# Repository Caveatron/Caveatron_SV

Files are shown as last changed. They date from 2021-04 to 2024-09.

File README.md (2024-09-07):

# Caveatron SV
 Survey-focused Caveatron model without LIDAR

## Key Features

- Electronic cave survey device
- Laser rangefinder up to 40 m
- Integrated digital compass and inclinometer
- LRUD and basic passage walls points measurements
- Fast Teensy processor
- File transfer to PC over USB
- Water/dust resistant 3D printed enclosure
- Custom printed circuit board

## What's New (2024-09-07)

SV Rev C is the current and preferred version and is the only one in active development. This version uses the faster Teensy 4.1 processor and has several enhancements including a new magnetometer module for much improved compass accuracy and reliability, a capacitive touchscreen, and faster battery charging.
A new revision of the Rev C board (C.2) has been posted with an RTC battery enhancement along with an updated bill of materials.

SV Rev A is based on the older Teensy 3.6 processor and is now deprecated and some components may no longer be available.

## Summary of Caveatron SV Directory Contents for each Revision

### Documentation
- Bill of Materials
- Assembly Instructions
- Wire Harness Assembly Instructions
- 3D Printed Parts Description

### PCB
- Schematic diagram
- KiCad files
- PCB gerber files

### Mechanical
- STL files for all 3D printed parts
- STEP files for all 3D printed parts

## These items can be found in other folders:

### Calibration
Info and calculators can be found at https://github.com/Caveatron/Calibration

### Software
Software can be found at https://github.com/Caveatron/Software

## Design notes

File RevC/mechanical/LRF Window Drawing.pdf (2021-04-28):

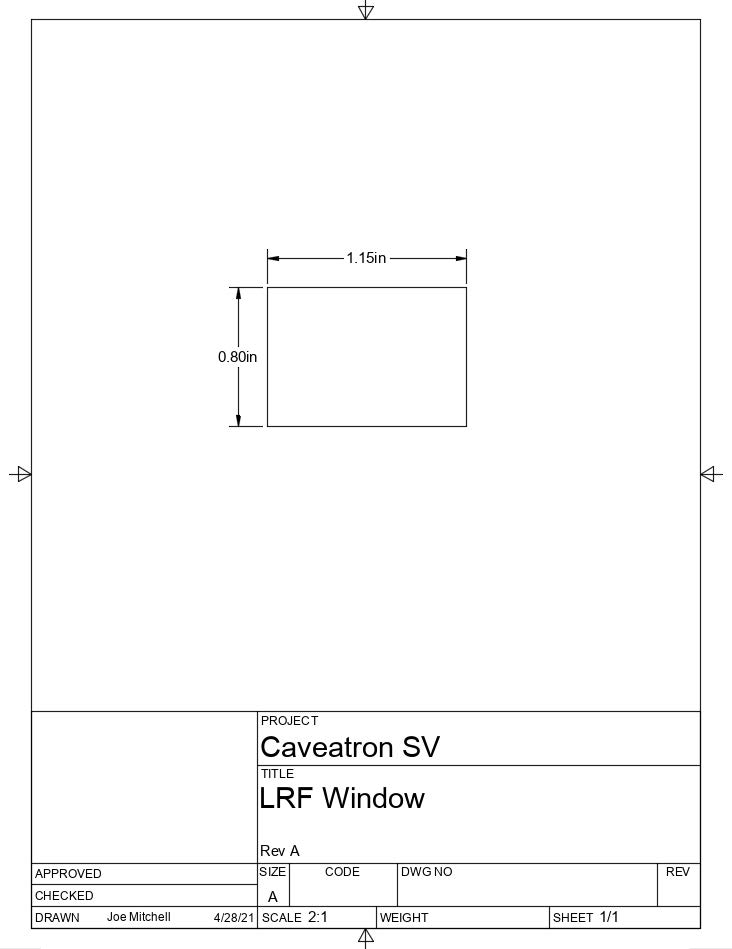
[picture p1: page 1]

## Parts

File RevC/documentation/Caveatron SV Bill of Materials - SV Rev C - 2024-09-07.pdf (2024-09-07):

### Caveatron SV Bill of Materials

Hardware Revision: C
Date: 2024-09-07
Item | Qty | Manufacturer | Mfr. P/N | Description | Suggested Vendor Link | Photo
Main Processor | 1 | PJRC Electronics | Teensy 4.1 | Teensy 4.1 | PJRC Store (https://www.pjrc.com/store/teensy41_pins.html)

Notes: The main system processor. Available from multiple vendors. Versions with and without the pins pre-installed are available (link above is with pins). Either of the versions (with or without Ethernet) are fine.
Touchscreen
LCD
1 | BuyDisplay | N/A | LCD 3.5” 320x480 TFT Display Module, OPTL Touch Screen w/Breakout Board
| | | Options: -Capacitive touch panel -16-bit 8080 40-pin header -3.3V supply -No font chip

BuyDisplay (https://www.buydisplay.com/lcd-3-5-inch-320x480-tft-display-module-optl-touch-screen-w-breakout-board)

Notes: The display and user interface. Note that this is the capacitive touchscreen version unlike the resistive version used previously.

Item | Qty | Manufacturer | Mfr. P/N | Description | Suggested Vendor Link
Photo

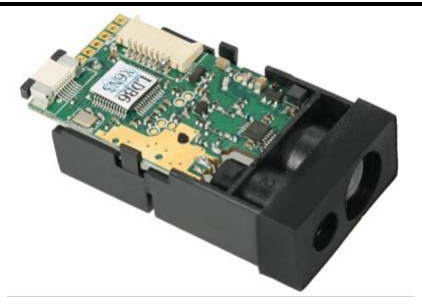
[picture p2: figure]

Laser Rangefinder | 1 | JRT Meter Tech., Co, Ltd. | Unknown | 40m – 60m Laser Distance Sensor Module | Egismos (https://www.egismos.com/laser-measuring-optoelectronics-module/laser-range-finder-distance-meter-4M) (HEX) Ebay (https://www.ebay.com/itm/314273830602) (ASCII) Alibaba (https://www.alibaba.com/product-detail/M88B-40m-Cheap-OEM-Chengdu-JRT_60644767746.html) (HEX) Alibaba (https://www.alibaba.com/product-detail/M88B-60m-Measuring-Sensor-Range-Finder_1600250111785.html) (HEX) Alibaba (https://www.alibaba.com/product-detail/Laser-Distance-Manufacturers-JRT-Smart-Distance_1600062036577.html) (probably HEX)
| | | | | Availability changes frequently. Sites linked above has availability as of the date of this BOM

Notes: Used for station distance measurements. There are several variants of this module including those that use ASCII or HEX-based commands both of which are supported by the Caveatron. Based on the datasheets I have reviewed I think any variant of this style should work.
Font/Graphics IC | 1 | Winbond | W25Q128JVSIM | W25Q128 SPI flash memory IC, 128 Mbit, quad 8-SOIC | Digikey (https://www.digikey.com/en/products/detail/winbond-electronics/W25Q128JVSIM/6819721) and many other source

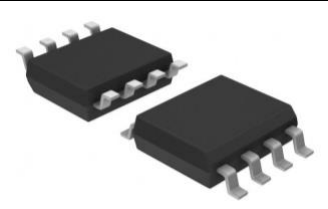
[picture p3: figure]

Notes: Contains the fonts and graphics used for the GUI. You must use the 128Mbit 8-SOIC package version – other sizes may not work. It is soldered to the pad location on the underside of the Teensy 4.1 that is directly under the micro-SD slot and farther from the edge (adjacent to the cross row of pins).

Item | Qty | Manufacturer | Mfr. P/N | Description | Suggested Vendor Link | Photo
Compass Module Optional but HIGHLY RECOMMENDED | 1 | Witmotion | RM3100 | WitMotion High-Precision RM3100 Military-grade Magnetometer Sensor | Amazon (https://www.amazon.com/High-Accuracy-Magnetometer-Geomagnetism-Military-Grade-High-Revolution/dp/B01N5QL0XC/) or Witmotion (https://www.wit-motion.com/geomagnetic-sensor/witmotion-high-precision-rm3100-military.html)

Notes: Used to determine the azimuth angle of the Caveatron. This is the best currently available low-cost magnetometer module option. This magnetometer has proven more accurate, reliable and with less drift than another other tested. It is optional since the Pololu IMU module below also includes a magnetometer but the Pololu magnetometer is much more noisy and less accurate, so it is highly recommended that you use this module.

IMU Module

Required for
accelerometer but
magnetometer
portion can be used
instead of RM3100
(not as good as
RM3100)
1 | Pololu | MinIMU-9 v5 (#2738)

MinIMU-9 v5 Gyro,
Accelerometer, Compass
(LSM6DS33, and LIS3MDL
Carrier)

Pololu (https://www.pololu.com/product/2738)

Notes: Used to determine orientation of the Caveatron and measure inclination.

Item | Qty | Manufacture r | Mfr. P/N | Description | Suggested Vendor Link | Photo
Battery Charger Module | 1 | Unknown | TP5000 | Lithium Ion 3.7V Charger Module | Amazon (https://www.amazon.com/Comimark-Charger-Lithium-LiFePO4-Charging/dp/B07XM7WT5M)

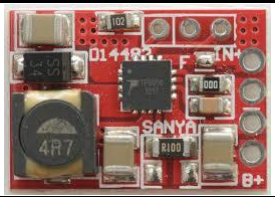
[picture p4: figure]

Notes: Battery charging module. There are several sources for this module and at least 2 variants. Be sure to get the variant with the 4 power pins all on the same side. A solder bridge is required to make it functional and a 0.2 ohm resistor can be added to increase the charge current above 1 Amp. These are usually on a red PCB but can also be green from other sources.
10k resistor | 2 | Various | Various | SMD resistor, 10k-ohm, 1%, 1206 package

Digikey (https://www.digikey.com/en/products/detail/stackpole-electronics-inc/RMCF1206FT10K0/1759669)

Notes: Resistor for battery monitor voltage divider and for IMU power input. Available from numerous manufacturers and vendors - the above is only 1 example. ¼ watt or less is fine since this carries no significant current.
3.3k resistor | 1 | Various | Various | SMD resistor, 3.3k-ohm, 1%, 1206 package

Digikey (https://www.digikey.com/en/products/detail/stackpole-electronics-inc/RMCF1206FT3K30/1753917)

Notes: Resistor for battery monitor voltage divider. Available from numerous manufacturers and vendors - the above is only 1 example. ¼ watt or less is fine since this carries no significant current.

Item | Qty | Manufacturer | Mfr. P/N | Description | Suggested Vendor Link | Photo
Battery Pack OPTION 1 | 1 | Dantona | L37A26-1-0-2WX | 18650 Lithium-Ion Battery Rechargeable (Secondary) 2.6Ah | Digikey (https://www.digikey.com/en/products/detail/dantona-industries/L37A26-1-0-2WX/13692682)

Notes: Primary system battery. This version comes with a 2-pin JST connector. A similar battery is available from Tenergy (PN 30011) but is not connectorized: Tenergy (https://power.tenergy.com/tenergy-li-ion-3-7v-2600mah-rechargeable-battery-pack-w-pcb-1s1p-9-62wh-3-5a-rate/) Battery Pack

OPTION 2

1 | Adafruit | 1781 | Lithium Ion Cylindrical Battery - 3.7v 2200mAh

Adafruit (https://www.adafruit.com/product/1781)

Notes: Primary system battery. This option is a lower capacity battery but might be an option if you are unable to obtain the higher capacity option above. Voltage
Regulator –
5V
1 | Pololu | 2119 | 5V Step-Up/Step-Down Voltage Regulator S7V7F5

Pololu (https://www.pololu.com/product/2119)

Notes: Power supply for Teensy. LRF
Voltage
Regulator
1 | Pololu | 2118 | Pololu Adjustable Step- Up/Step-Down Voltage Regulator S7V8A

Pololu (https://www.pololu.com/product/2118)

Notes: Power supply for Laser Rangefinder. Output needs to be set to 3.0V.

Item | Qty | Manufacturer | Mfr. P/N | Description | Suggested Vendor Link | Photo
Power Switch Module | 1 | Pololu | 2808 | Mini Pushbutton Power Switch with Reverse Voltage Protection, LV | Pololu (https://www.pololu.com/product/2808)

Notes: Turns on and off system power when pushbutton power switch is pressed and also controls timed auto power-off. 2.8V Voltage
Regulator

USED IN
PCB SV
REV C.2
1 | Microchip Technology

MCP1700-
2802E/TO

Linear voltage regulator IC, 2.8V, 250mA, TO92

Digikey (https://www.digikey.com/en/products/detail/microchip-technology/MCP1700-2802E-TO/2614902)

Notes: Regulates battery voltage to keep Real Time Clock active when Caveatron is turned off. Replaces coin cell battery used in PCB Rev C.2. 1uF Ceramic
Capacitor

USED IN
PCB SV
REV C.2
2 | TDK | FG18X7R1 E105KRT0
| | 6

Ceramic Capacitor, 1uF, 25V, Radial leads

Digikey (https://www.digikey.com/en/products/detail/tdk-corporation/FG18X7R1E105KRT06/5802875) (and
many others)

Notes: Stabilizes output voltage of RTC regulator above. Most any ceramic capacitor of 1 uF will work so long as it is rated to 6V or higher. Piezoelectric
Buzzer
1 | Uxcell | A1406240 0ux0199

uxcell A14062400ux0199 5 Pcs DC 2-28V 80Db Sound
Electronic Passive Buzzer Alarm Black, 22 x 4.5 mm

Amazon (https://www.amazon.com/gp/product/B01AJOESXG)

Notes: Indicator buzzer.

Item | Qty | Manufacturer | Mfr. P/N | Description | Suggested Vendor Link | Photo
| | Adafruit | 3350 | | Adafruit (https://www.adafruit.com/product/3350) Amazon (https://www.amazon.com/Momentary-Tri-Color-Button-Illuminated-Stainless/dp/B09FDD9KR9)

Power Switch
& Charging
LED

1

Rugged Metal Pushbutton -
16mm RGB Momentary

CIT Relay and
Switch
BH16NBSBG | Digikey (https://www.digikey.com/en/products/detail/cit-relay-and-switch/BH16NBSBG/12503457)

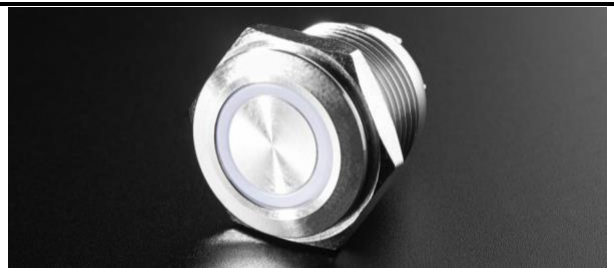
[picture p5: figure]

Notes: On/Off power switch and charge indicating ring LED. This one enables separate colors on the ring LED for indicating charging and charge complete. These can be found at other sources as well but if you buy from another source be sure to get the common anode version.
USB Jack | 1 | GT Contact | GT11A200-10 (RR-11A200-10)

Micro USB-B Plastic Panel
Mount to 6 Pin Solder Type

USBFirewire.
com (https://www.usbfirewire.com/parts/rr-11a200-10.html)

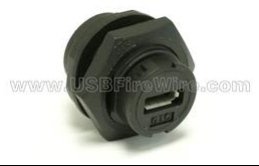
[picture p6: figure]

Notes: USB jack for data download, battery charging, and loading of software and calibration parameters. This is the version with the solder pins on the back side. If you prefer a USB-mini connector, that is available as part number RR-114200-10 (https://www.usbfirewire.com/parts/rr-114200-10.html) and is an identical fit.

Item | Qty | Manufacturer | Mfr. P/N | Description | Suggested Vendor Link | Photo

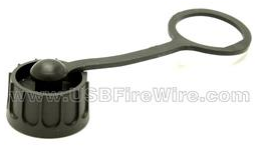
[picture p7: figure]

USB Cap | 1 | GT Contact | GT1C522122 (RR-1C522122) | Seal Cap | USBFirewire. com (http://www.usbfirewire.com/parts/rr-1c522122.html#RR-1C522122)

Notes: Waterproof cap for USB jack. This cap works for either the mini or micro USB options.

Item | Qty | Manufacturer | Mfr. P/N | Description | Suggested Vendor Link | Photo
GPS Module OPTIONAL (OPTION 1) | 1 | Adafruit | 746 | Adafruit Ultimate GPS Breakout - 66 channel w/10 Hz updates - PA1616S | Adafruit (https://www.adafruit.com/product/746) Digikey (https://www.digikey.com/en/products/detail/adafruit-industries-llc/746/5353613) and other sources

Notes: GPS module. This component adds GPS functionality to the Caveatron for marking entrances or surface features. Data is saved with the cave survey file and includes latitude, longitude, elevation, and position accuracy. Use of this module precludes use of the Bluetooth modules below.
Bluetooth
Module

OPTIONAL
(OPTION 2)
1 | Various | HM-10 | HM-10 Bluetooth Serial Module

Amazon (https://www.amazon.com/gp/product/B01G9KSAF6)

Notes: Bluetooth communications module. This component is intended for future interfacing with TopoDroid or similar software running on an Android tablet but this function has not yet been added. The HM-10 is a Bluetooth 4.0 LE device so is only compatible with newer tablets and draws less power. Multiple variants and vendors are available for this component and so long as it is an HM-10 and operates on +5V, it should work. Use of this module precludes use of the GPS module above.
Bluetooth
Module

OPTIONAL
(OPTION 3)
1 | Various | HC-05 | HC-05 Bluetooth Serial Module

Amazon (https://www.amazon.com/gp/product/B01G9KSAF6)

Notes: Bluetooth communications module. This component is intended for future interfacing with TopoDroid or similar software running on an Android tablet but this function has not yet been added. The HC-05 is a Bluetooth 2.0 device so is compatible with older tablets but draws more power. Multiple variants and vendors are available for this component and so long as it is an HC-05 and operates on +5V, it should work. Use of this module precludes use of the GPS module above.

MicroSD
Card
1 | Various | Various | SanDisk 32GB Ultra microSDHC UHS-I Memory Card

Amazon (https://www.amazon.com/dp/B073JWXGNT/)
and many other
sources

Notes: Storage for Caveatron data. Numerous brands and sources available. MicroSD card must be SDHC type not larger than 32 GB (smaller capacities are fine as well). SanDisk brand is preferred as they are generally the most reliable.
Item | Qty | Manufacturer | Mfr. P/N | Description | Suggested Vendor Link | Photo
Teensy USB connector | 1 | N/A | N/A | Micro USB Male Solder Connector | Amazon (https://www.amazon.com/Micro-USB-Connector-Conwork-Replacement/dp/B072MCHGXK) and many other sources

Notes: For the cable to connect the exterior USB jack to the Teensy. Wires are soldered between this part and the USB jack connector pins. Note that only the D+, D-, and GND are connected on this plug. The USB power (and a second GND wire) goes from the USB jack to a plug on the main PCB.

LCD
Connector
Cable
1 | N/A | N/A | 40 pin IDE Male to Female Extension Cable, 4” (10 cm) or 6” (15 cm)

Ebay (https://www.ebay.com/itm/170709721128)

and other sources

Notes: Cable to connect to LCD Touchscreen from the Caveatron main board. Cables longer than 6” would take up too much space in the enclosure while those shorter than 4” are not long enough. These are available from multiple vendors. Note that some of these connectors do not include one of the middle pins, however those are fine since that pin is not used.

Item | Qty | Manufacturer | Mfr. P/N | Description | Suggested Vendor Link | Photo
JST Connector 5-pin | 2 or 3 | Various | JST-XH | JST 2.54mm pitch, 5 pin, male connector | Amazon, Ebay and others

Notes: Connector for LRF and power switch. If you order them prewired as in the photo, be sure they are at least 100 mm in length. JST
Connector
2-pin
3 or 4 | Various | JST-XH | JST 2.54mm pitch, 2 pin, male connector

Amazon, Ebay and
others

Notes: Connector used for USB data, USB power, piezo buzzer, and battery. If you order them prewired as in the photo, be sure they are at least 100 mm in length. (You won’t need one for the battery if you order a battery that is pre-connectorized.
Socket
Headers 1

1
(6 pin
positions
needed)

Prec-Dip or
others

310-87-
106-41-
001101

Socket header, 0.1” pitch, 4.2 mm insulation height,
single row, 6 pins

Digikey (https://www.digikey.com/en/products/detail/preci-dip/310-87-106-41-001101/3757345)
and others

Notes: Header sockets for RM3100 magnetometer. Only needed if you are using the RM3100. Short header needed since the RM3100 has tall components. This header size is matched to the RM3100 brackets. Other variants with different numbers of pins are available. 4 pins are needed on one side and 2 pins on the other.
Socket
Headers 2

3
(54 pin
positions
needed)

Prec-Dip or
others

801-87-
024-10-
001101

Socket header, 0.1” pitch, 7.0 mm insulation height,
single row, 24 pins

Digikey (https://www.digikey.com/en/products/detail/preci-dip/801-87-024-10-001101/3757459)
and others

Notes: Header sockets for Teensy and IMU. Optional but this shorter size is preferred over the more common 8.51mm height to avoid interference with the display. Other variants with different numbers of pins are available. Two sets of 24 pins and 1 additional pin are needed for the Teensy and 5 pins are needed for the IMU module.

Item | Qty | Manufacturer | Mfr. P/N | Description | Suggested Vendor Link | Photo
Screen Protector | 1 | Supershieldz | N/A | iPhone SE and iPhone 5 Screen Protector | Amazon (https://www.amazon.com/gp/product/B00EOYMO66/)

Notes: Protection film for touchscreen. Needs to be cut to length. Most any PET screen protector film for iPhone 4, 4S, 5, 5s, or SE should work as they have the same screen width as the 3.5” LCD. Multiple vendors produce a similar product.
Threaded
Inserts for
Enclosure
4 | Initeq | #6-32 Threaded Heat Set Inserts for 3D Printing (Long)

Ebay (https://www.ebay.com/itm/20-pcs-6-6-32-Threaded-Heat-Inserts-for-3D-Printing-Plastic-Metal-6-32-Long/292301193578)

Notes: Heat set threaded inserts used in 3D printed enclosure. Threaded
Inserts for
external
mounting
(Optional)
1 | Initeq | #1/4-20 1/4" Threaded Heat Set Inserts for 3D Printing (Short)

Ebay (https://www.ebay.com/itm/20x-1-4-20-Brass-Threaded-Heat-Set-Inserts-for-Plastic-3D-Printing-Brass-Metal/292349851049)

Notes: Heat set threaded inserts used in 3D printed enclosure for external mounting. This is an optional part if you plan to attach something external to the Caveatron (like a handle) or mount it to a tripod.

Item | Qty | Manufacturer | Mfr. P/N | Description | Suggested Vendor Link | Photo
LRF Window Material | 1 | Sibe Polymers | 5064981212 | Clear Acrylic Plexiglass 12" x 12" - 3/32" (.090) | Amazon (https://www.amazon.com/gp/product/B01KABODQK/)

Notes: Transparent acrylic sheet for LRF window on Main Body. Wrist Strap
Lanyard
1 | Hukado | N/A | Hukado Adjustable Hand Wrist Straps Lanyard, (6 Pack) 9.5 inches Nylon Lanyard

Amazon (https://www.amazon.com/gp/product/B07Q2QDG3Q)

Notes: Wrist Strap. This wrist strap works well, but other options are available in various lengths depending on your preference.

O-Ring
Seals

4
feet

The O-Ring
Store
N50.103 | 0.103" (2.62mm) Buna-N 50 O-Ring Cord Stock, Black

O-Ring Store (https://www.theoringstore.com/store/index.php?main_page=product_info&cPath=117_527&products_id=40240)

Notes: O-Ring material for seals in main enclosure and LIDAR module. This 50 durometer material is preferred over more readily available 70 durometer since it is softer and can make a tighter seal. Must cut to length and glue ends (this vendor also sells O-ring glue in small quantities.) Other vendors sell similar material.

RTC Battery Holder

NOT
RECOMMENDED
Only used with
PCB SV Rev C.1

1 MPD and
others

BC501SM Coin Cell Battery Holder -12mm
(for CR1220 batteries)

Digikey (https://www.digikey.com/en/products/detail/mpd-memory-protection-devices/BC501SM/2439260)

Amazon (https://www.amazon.com/QMseller-CR1220-Horizontal-Battery-Container/dp/B07GXTQN75)

Notes: Holds a CR1220 battery to provide power to maintain the Real-time clock on the Teensy. The CR1220 batteries can only run the real-time clock for 6 weeks so require frequent replacement. A mod has been implemented to replace this part with a regulator and this part has been removed from PCB C.3 and C.4. Identical holders are available from many sources with differing part numbers.

Other Required Items:
Caveatron SV Rev C Printed Circuit Board
Single row male headers, 2.54 mm (0.1”) pitch
Double row female headers 2x20 (for 40 pin LCD Connector), 2.54 mm (0.1”) pitch Soldering supplies
6-32 x 1/2” Flat Head Screws (4x)
4-20 x ½” thread rolling screws (3x)
4-20 x ¼” thread rolling screws (10x) 2-28 x ¼” thread rolling screws (15x) PETG filament for 3D printed parts O-Ring grease
O-Ring epoxy
Flexible waterproof epoxy sealant Adhesive-backed foam
Tape (Kapton or cellophane)

Notes: For assembly and electrical interconnections between boards.

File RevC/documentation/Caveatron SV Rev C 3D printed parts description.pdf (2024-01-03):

## Caveatron SV Rev C 3D Printed Parts Description

2024-01-02

### Introduction

This document includes a description of the 3D printed parts for the Caveatron SV and notes on how to print them. Also included is information on how the 3D printed parts go together. Information on how to assemble all the other components is found in the Caveatron SV Assembly Instructions document.

### Scaling

In some Slicer software, these files must be scaled by 2540% though in others, they import correctly.

### General Printing Notes

The recommended material for these parts is PETG. Print settings were 0.2 mm resolution and 20% infill. PLA is not recommended as it is not as durable. ABS may work but is more rigid and brittle so screws and inserts may not work as well. Many parts can be printed without support material. There are a few parts where support material is recommended in a few spots and if you have the ability to insert supports only in selected locations, you do not need supports everywhere.

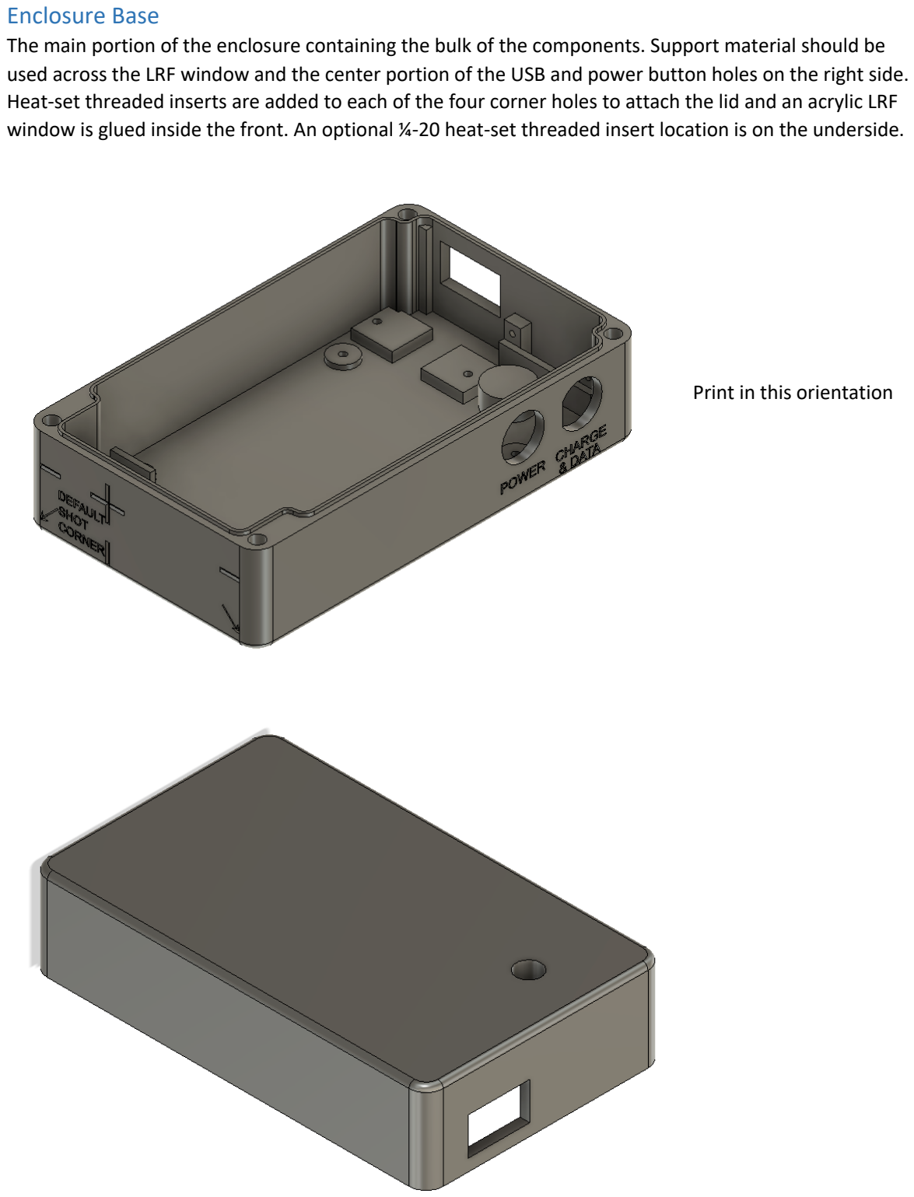
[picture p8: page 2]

### Enclosure Base

The main portion of the enclosure containing the bulk of the components. Support material should be used across the LRF window and the center portion of the USB and power button holes on the right side. Heat-set threaded inserts are added to each of the four corner holes to attach the lid and an acrylic LRF window is glued inside the front. An optional ¼-20 heat-set threaded insert location is on the underside.

Print in this orientation

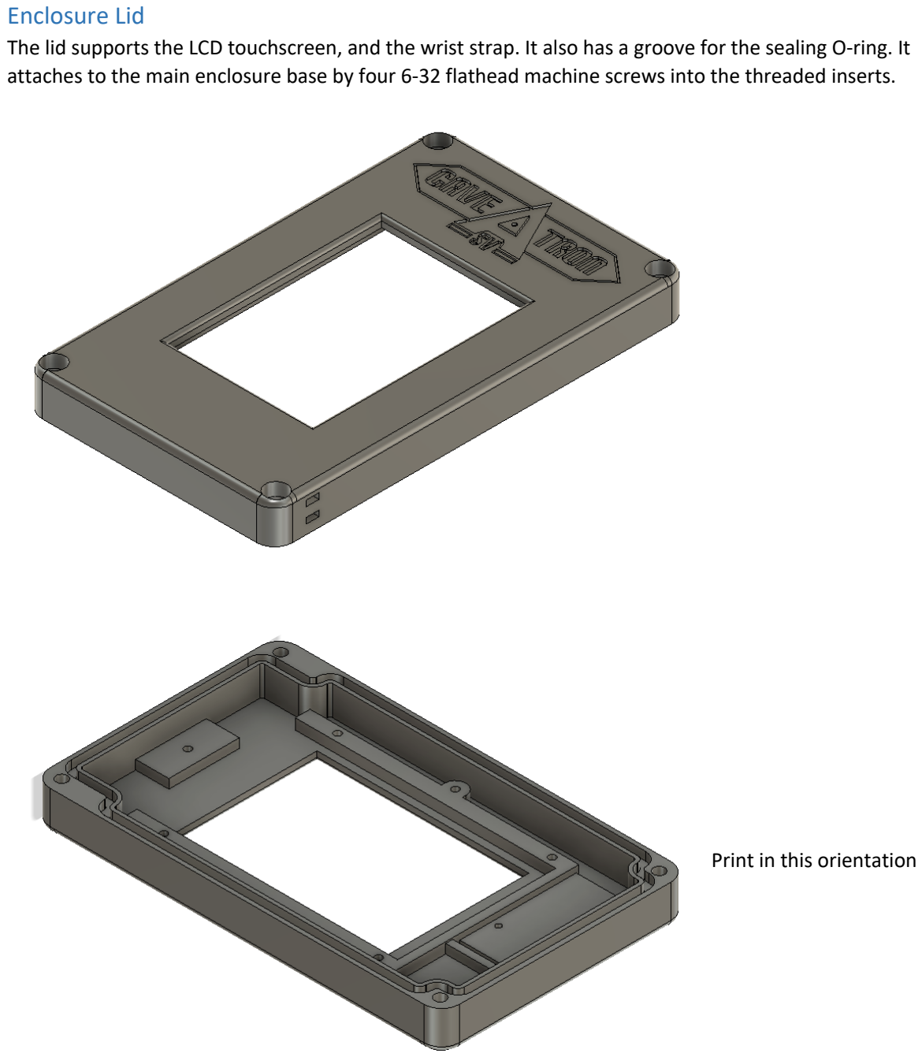
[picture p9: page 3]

### Enclosure Lid

The lid supports the LCD touchscreen, and the wrist strap. It also has a groove for the sealing O-ring. It attaches to the main enclosure base by four 6-32 flathead machine screws into the threaded inserts.

Print in this orientation

### LRF Cradle Bracket

The LRF module is supported by this bracket which in turn mounts to the inside of the Main Enclosure Base. A single 2-28 thread rolling screw inserted into the countersunk bottom center hole threads into the hole on the underside of the LRF module. The part is then mounted to the Main Enclosure base with two 4-20 thread rolling screws that are inserted into the countersunk holes on either side.

4-20 screws go in here; Toward LRF
The Cradle bracket attaches to the LRF

### LRF Clamp


Attaches to the top of the LRF bracket to fully secure the LRF module. Two 2-28 screws through the holes on either side attach to the top of the LRF bracket. The protrusion goes downward.

Flip over and 2-28 screw go through the holes.

Print in this orientation

The LRF clamp installs
in the marked holes.

module via a 2-28 screw through this hole.

window

### RM3100 Bracket

Provides support to the RM3100 magnetometer. 2-28 screws from the underside the main PCB screw into the two centermost holes in this part.


### RM3100 Clamp

Hold the RM3100 magnetometer securely to the bracket to prevent movement.


Be sure to get the orientation correct and adjust it so that it does not press on any components on the RM3100 board. The sloped corner goes toward the 40 pin connector for the touchscreen display.

Print in this orientation

2-28 screw threads
into the RM3100

Print in this orientation

### LCD Clamp

Provides additional support to the long side of the LCD modules. Two of these need to be printed.


A 4-20 thread rolling screw inserts through the LCD Clamp into threads into the hole indicated. The clamp is oriented so that the recessed part is down facing the LCD.

4-20 screw inserted through
the LCD Clamp threads in here.

Print in this orientation


### Buzzer Clamp

Secures the piezo buzzer in place.


This piece presses against backside of piezo buzzer (which is inserted into a slot at the bottom of the Main Enclosure Base). The Buzzer Clamp attaches to the Main Enclosure Base via two 2-28 thread rolling screws threaded into mounting points on the front of the enclosure.


### MinIMU Bracket

Secures the MinIMU module to the PCB.


This part does not directly attach to any other 3D part but instead attaches between MinIMU module and holes in the main PCB. Two 2-28 thread-rolling screws are inserted through the main PCB into the underside. The MinIMU attaches using one screw from the top.

Print in this orientation

The Cradle bracket installs to the enclosure base at the marked holes.

### Battery Clamp

Secures the battery in place. This part is attached to the underside of the Main Enclosure Lid with a single 4-20 thread rolling screw. Two small pieces of adhesive-backed foam should be attached to the side that presses down on the battery.


### GPS Bracket (Optional)

Secures the GPS module in place on the underside of the Main Enclosure Lid.


Printing requires supports to be enabled. It attaches with two 2-28 thread-rolling screws.

### Bluetooth Module Clamp (Optional)

Secures the Bluetooth module in place on the underside of the Main Enclosure Lid.


The cutout in this part fits over the Bluetooth module and holds it to the underside of the lid. It attaches with two 2-28 thread-rolling screws.

Print in this orientation

Print in this orientation

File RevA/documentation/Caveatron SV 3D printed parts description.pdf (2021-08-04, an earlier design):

## Caveatron SV Rev A 3D Printed Parts Description

2021-08-03

### Introduction

This document includes a description of the 3D printed parts for the Caveatron SV and notes on how to print them. Also included is information on how the 3D printed parts go together. Information on how to assemble all the other components is found in the Caveatron SV Assembly Instructions document.

### Scaling

To print properly, these files must be scaled by 2540% in your slicer software.

### General Printing Notes

The recommended material for these parts is PETG. Print settings were 0.2 mm resolution and 20% infill. PLA is not recommended as it is not as durable. ABS may work but is more rigid and brittle so screws and inserts may not work as well. Many parts can be printed without support material. There are a few parts were support material is recommended in a few spots and if you have the ability to insert supports only in selected locations, you do not need supports everywhere.


### Enclosure Base

The main portion of the enclosure containing the bulk of the components. Support material should be used across the LRF window and the center portion of the USB and power button holes on the right side. It contains holes for the heat-set threaded inserts for the lid screws and the option tripod mount.

Print in this orientation


### Enclosure Lid

The lid supports the LCD touchscreen, and the wrist strap. It also has a groove for the sealing O-ring. It attaches to the main enclosure base by four 6-32 flathead machine screws into the threaded inserts.

Print in this orientation

### LRF Cradle Bracket

The JRT LRF is placed into this bracket which attaches it to the Main Enclosure Base.

The Cradle bracket attaches to the LRF module via a screw through this hole.

A through-hole from the underside allows a 2-28 thread-rolling screw to be screwed into the hole in the LRF module. Two through holes on either side are for two 4-20 thread-rolling screws to affix the bracket to the Main Enclosure Base. The additional small holes on top are for attaching the LRF clamp. Note the orientation of the bracket when attaching the LRF and installing it into the Main Enclosure Base. The centered through-hole for the LRF needs to be toward the front window of the enclosure.

Print in this orientation

The LRF clamp installs
in the marked holes.


### LRF Clamp

Secures the LRF module in place.

It is flipped over from the orientation shown here to install on the top of the LRF cradle bracket using two 2-28 thread rolling screws. Be sure that the step at the rear of the part is downward and wraps over the similar step on the LRF itself.

Print in this orientation

The Cradle bracket installs to the enclosure base at the marked holes.

### LCD Clamp

Provides additional support to the long side of the LCD modules. Two of these need to be printed.


A 4-20 thread rolling screw inserts through the LCD Clamp into threads into the hole indicated. The clamp is oriented so that the recessed part is down facing the LCD.
4-20 screw inserted through the LCD Clamp threads in here.

Print in this orientation


### Buzzer Clamp

Secures the piezo buzzer in place.


This piece presses against backside of piezo buzzer (which is inserted into a slot at the bottom of the Main Enclosure Base). The Buzzer Clamp attaches to the Main Enclosure Base via two 2-28 thread rolling screws threaded into mounting points on the front of the enclosure.


### AltIMU Bracket

Secures the MinIMU or AltIMU module to the PCB.


This part does not directly attach to any other 3D part but instead attaches between IMU module and holes in the PCB using 2-28 thread-rolling screws inserted from the bottom of the PCB. One or two screws attach the IMU module to the bracket from the top. The MinIMU uses only one of the top screw holes in the bracket whereas the AltIMU uses both bracket holes.

Print in this orientation

The Cradle bracket installs to the enclosure base at the marked holes.

### Battery Clamp

Secures the battery in place. This part is attached to the underside of the Main Enclosure Lid with a single 4-20 thread rolling screw. Two small pieces of adhesive-backed foam should be attached to the side that presses down on the battery.


### Bluetooth Module Clamp (Optional)

Secures the Bluetooth module in place on the underside of the Main Enclosure Lid.


The cutout in this part fits over the Bluetooth module and holds it to the underside of the lid. It attaches with two 2-28 thread-rolling screws.

Print in this orientation

Print in this orientation

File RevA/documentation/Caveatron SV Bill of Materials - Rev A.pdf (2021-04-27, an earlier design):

### Caveatron SV Bill of Materials

Hardware Revision: A

### Date: 2021-04-18

All the parts in this list have been tested with the Caveatron and have either been integrated into the code or are planned to be. For some parts, alternate options are available.

Touchscreen LCD; BuyDisplay; LCD 3.5” 320x480; TFT Display Module, OPTL Touch Screen w/Breakout Board; Options: -Resistive touch panel -16-bit 8080 40-pin header -3.3V supply -No font chip; Notes: The display and user interface.

Item | Qty | Manufacturer | Mfr. P/N | Description | Suggested Vendor Link | Photo
Main Processor | 1 | PJRC Electronics | Teensy 3.6 | Teensy 3.6 | PJRC Store (https://www.pjrc.com/store/teensy36_pins.html)

Notes: The main system processor. Available from multiple vendors. Versions with and without the pins pre-installed are available (link above is with pins).

Item | Qty | Manufacturer | Mfr. P/N | Description | Suggested Vendor Link | Photo
Graphics Module (SPI Flash Memory) | 1 | Multiple (Winbond IC) | W25Q64 or similar | W25Q64 64Mbit 8MByte Flash Memory Module Data Flash SPI Interface | Amazon (https://www.amazon.com/NOYITO-W25Q64-64Mbit-DataFlash-Interface/dp/B07C4JN857)

Notes: Storage for fonts and graphics used in the GUI. SPI Flash memory must be Winbond W25Q32, W25Q64, or W25Q128 (memory size should be 32Mbit or higher.) Winbond W25Q16 (16 Mbit) could be used, but will only hold the fonts and not support the graphics.

Laser
Rangefinder

OPTION 3

1 | JRT Meter
Tech., Co, Ltd.
Unknown | 40m – 60m Laser
Distance Sensor
Module

Ebay (https://www.ebay.com/itm/laser-distance-meter-serial-module-TTL-RS232-laser-meter-sensor/292329869069)
Availability changes
frequently. Site
linked above has
availability as of the
date of this BOM

Notes: Used for station distance measurements. There are several variants of this module. Be sure to get the small one that is about 50 mm(2”) in length.

IMU/
Compass
Module

OPTION 1

1 | Pololu | MinIMU- 9 v5 (#2738)
| | Or
| | AltIMU- 10 v5 (#2739)

AltIMU-10 v3 Gyro,
Accelerometer,
Compass, and Altimeter
(L3GD20H, LSM303D,
and LPS331AP Carrier)

Pololu (https://www.pololu.com/product/2738)

Notes: Used to determine orientation of the Caveatron and measure azimuth and inclination. This is the best currently available IMU module option although the discontinued models below have half the noise floor if you can find them. The AltIMU-10 v5 is an equivalent part and can also be used (the altitude sensor is not used).

Item | Qty | Manufacturer | Mfr. P/N | Description | Suggested Vendor Link | Photo
Battery Pack OPTION 1 | 1 | Dantona | L37A26-1-0-2WX | 18650 Lithium-Ion Battery Rechargeable (Secondary) 2.6Ah | Digikey (https://www.digikey.com/en/products/detail/dantona-industries/L37A26-1-0-2WX/13692682)

Notes: Primary system battery. This version comes with a 2-pin JST connector. A similar battery is available from Tenergy (PN 30011) but is not connectorized: Tenergy (https://power.tenergy.com/tenergy-li-ion-3-7v-2600mah-rechargeable-battery-pack-w-pcb-1s1p-9-62wh-3-5a-rate/) Battery Pack

OPTION 2

1 | Adafruit | 1781 | Lithium Ion Cylindrical Battery - 3.7v 2200mAh

Adafruit (https://www.adafruit.com/product/1781)

Notes: Primary system battery. This option is a lower capacity battery but might be an option if you are unable to obtain the higher capacity option above. Bluetooth
Module

OPTIONAL
(OPTION 1)
1 | Various | HM-10 | HM-10 Bluetooth Serial Module

Amazon (https://www.amazon.com/gp/product/B01G9KSAF6)

Notes: Bluetooth communications module. This component is intended for future interfacing with TopoDroid or similar software running on an Android tablet but this function has not yet been added. The HM-10 is a Bluetooth 4.0 LE device so is only compatible with newer tablets and draws less power. Multiple variants and vendors are available for this component and so long as it is an HM-10 and operates on +5V, it should work.
Bluetooth
Module

OPTIONAL
(OPTION 2)
1 | Various | HC-05 | HC-05 Bluetooth Serial Module

Amazon (https://www.amazon.com/gp/product/B01G9KSAF6)

Notes: Bluetooth communications module. This component is intended for future interfacing with TopoDroid or similar software running on an Android tablet but this function has not yet been added. The HC-05 is a Bluetooth 2.0 device so is compatible with older tablets but draws more power. Multiple variants and vendors are available for this component and so long as it is an HC-05 and operates on +5V, it should work.

Item | Qty | Manufacturer | Mfr. P/N | Description | Suggested Vendor Link | Photo
Battery Charger Module | 1 | Unknown | Unknown | Lithium Ion 3.7V Charger Module | Amazon (https://www.amazon.com/Comimark-Charger-Lithium-LiFePO4-Charging/dp/B07XM7WT5M)


Notes: Battery charging module. There are several sources for this module and at least 2 variants. Be sure to get the variant with all the 4 power pins all on the same side to work with the Caveatron SV PCB. These are usually on a red PCB.

10k resistor | 2 | Various | Various | SMD resistor, 10k-ohm, 1%, 1206 package

Digikey (https://www.digikey.com/en/products/detail/stackpole-electronics-inc/RMCF1206FT10K0/1759669)


Notes: Resistor for battery monitor voltage divider and IMU power input. Available from numerous manufacturers and vendors - the above is only 1 example. ¼ watt or less is fine since this carries no significant current.

3.3k resistor | 1 | Unknown | Unknown | SMD resistor, 3.3k-ohm, 1%, 1206 package

Digikey (https://www.digikey.com/en/products/detail/stackpole-electronics-inc/RMCF1206FT3K30/1753917)


Notes: Resistor for battery monitor voltage divider. Available from numerous manufacturers and vendors - the above is only 1 example. ¼ watt or less is fine since this carries no significant current.

Item | Qty | Manufacturer | Mfr. P/N | Description | Suggested Vendor Link | Photo


Voltage Regulator – 5V | 1 | Pololu | 2119 | 5V Step-Up/Step-Down Voltage Regulator S7V7F5 | Pololu (https://www.pololu.com/product/2119)

Notes: Power supply for Teensy.


Voltage
Regulator –
Adjustable
1 | Pololu | 2118 | Pololu Adjustable Step- Up/Step-Down Voltage Regulator S7V8A

Pololu (https://www.pololu.com/product/2118)

Notes: Power supply for Laser Rangefinder. Output needs to be set to 3.0V.

Power
Switch
Module
1 | Pololu | 2808 | Mini Pushbutton Power Switch with Reverse Voltage Protection, LV

Pololu (https://www.pololu.com/product/2808)


Notes: Turns on and off system power when pushbutton power switch is presses and also controls timed auto power-off.

Item | Qty | Manufacturer | Mfr. P/N | Description | Suggested Vendor Link | Photo


Piezoelectric Buzzer | 1 | Uxcell | A1406240 0ux0199 | uxcell A14062400ux0199 5 Pcs DC 2-28V 80Db Sound Electronic Passive Buzzer Alarm Black, 22 x 4.5 mm | Amazon (https://www.amazon.com/gp/product/B01AJOESXG)

Notes: Indicator buzzer. This is a smaller size than the regular Caveatron buzzer

Power Switch
& Charging
LED
1 | Adafruit | 3350 | Rugged Metal Pushbutton - 16mm 6V RGB Momentary

Adafruit (https://www.adafruit.com/product/3350)

Amazon (https://www.amazon.com/gp/product/B07SLXNW15/)


Notes: On/Off power switch and charge indicating ring LED. This one enables separate colors on the ring LED for indicating charging and charge complete. Other 16mm momentary pushbutton switches from Adafruit are available with a single color LED, though they are longer in length, so may not fit well in the enclosure. If you buy from another source be sure to get the common anode version.

USB Jack | 1 | GT Contact | GT11420 0-10

Mini USB-B C2 size
Plastic Panel Mount

USBFirewire.
com (http://www.usbfirewire.com/parts/rr-114200-10.html#RR-114200-10)


Notes: Mini-USB jack for data download, battery charging, and loading of software and calibration parameters. This is the version with the solder pins on the inside.

Item | Qty | Manufacturer | Mfr. P/N | Description | Suggested Vendor Link | Photo
USB Cap | 1 | GT Contact | GT1C522 122 | Seal Cap | USBFirewire. com (http://www.usbfirewire.com/parts/rr-1c522122.html#RR-1C522122)

Notes: Waterproof cap for USB jack.

RTC Battery
Holder
1 | MPD and others

BC501S
M

Coin Cell Battery Holder
- 12mm
(for CR1220 batteries)

Digikey (https://www.digikey.com/en/products/detail/mpd-memory-protection-devices/BC501SM/2439260)

Amazon (https://www.amazon.com/QMseller-CR1220-Horizontal-Battery-Container/dp/B07GXTQN75)

Notes: Holds a CR1220 battery to provide power to maintain the Real-time clock on the Teensy 3.6. Identical holders are available from many sources with differing part numbers but those I have checked that are surface mount all have nearly identical dimensions so should work.

MicroSD
Card
1 | Various | Various | SanDisk 16GB Ultra microSDHC UHS-I Memory Card
Amazon (https://www.amazon.com/dp/B073K14CVB/)

Notes: Storage for Caveatron data. Numerous brands and sources available. MicroSD card must be SDHC type not larger than 32 GB. SanDisk brand is preferred as they are generally the most reliable.

Item | Qty | Manufacture r | Mfr. P/N | Description | Suggested Vendor Link | Photo
LCD Connector Cable | 1 | N/A | N/A | 40 pin IDE Male to Female Extension Cable, 4” (10 cm) or 6” (15 cm) | Ebay or Amazon

Notes: Cable to connect to LCD Touchscreen from the Caveatron main board. Cables longer than 6” would take up too much space in the enclosure while those shorter than 4” are not long enough. These are available from multiple vendors.

JST
Connector
5-pin
3 | Various | JST-XH | JST 2.54mm pitch, 5 pin, male connector
Amazon,
Ebay and
others

Notes: Connector for LRF, power switch, and Bluetooth module. If you order them prewired as in the photo, be sure they are at least 100 mm in length.

JST
Connector
2-pin

3 or
4
Various | JST-XH | JST 2.54mm pitch, 2 pin, male connector
Amazon,
Ebay and
others

Notes: Connector used for USB data, USB power, piezo buzzer, and battery. If you order them prewired as in the photo, be sure they are at least 100 mm in length. (You many not need one for the battery if you order a battery that is pre-connectorized

Item | Qty | Manufacturer | Mfr. P/N | Description | Suggested Vendor Link | Photo
Threaded Inserts for Enclosure | 10 | Initeq | | #6-32 Threaded Heat Set Inserts for 3D Printing (Long) | Amazon (https://www.amazon.com/gp/product/B077CH3GCM/)

Notes: Heat set threaded inserts used in 3D printed enclosure. Threaded
Inserts for
external
mounting
(Optional)
1 | Initeq | #1/4-20 1/4" Threaded Heat Set Inserts for 3D Printing (Short)

Amazon (https://www.amazon.com/gp/product/B077P4M1CM/)

Notes: Heat set threaded inserts used in 3D printed enclosure for external mounting. This is an optional part if you plan to attach something external to the Caveatron (like a handle) or mount it to a tripod.
2-28 Thread
Rolling
Screws
14 | Small Parts | 410 Stainless Steel Thread Rolling Screw for Plastic, Passivated Finish, Pan Head, Phillips Drive, #2-28 Thread Size, 1/4" Length

Amazon (https://www.amazon.com/gp/product/B00GDYAXM2/)

Notes: Screws for threading directly into 3D printed holes 4-20 Thread
Rolling
Screws
10 | Small Parts | 410 Stainless Steel Thread Rolling Screw for Plastic, Passivated Finish, Pan Head, Phillips Drive, #4-20 Thread Size, 1/4" Length

Amazon (https://www.amazon.com/gp/product/B00GDYB61Y/)

Notes: Screws for threading directly into 3D printed holes

Item | Qty | Manufacturer | Mfr. P/N | Description | Suggested Vendor Link | Photo
LRF Window Material | 1 | Sibe Polymers | 506498121 2 | Clear Acrylic Plexiglass 12" x 12" - 3/32" (.090) | Amazon (https://www.amazon.com/gp/product/B01KABODQK/)

Notes: Transparent acrylic sheet for Rangefinder window on Main Body. The 0.118” transparent acrylic sheets used for the LIDAR windows could be used as well if you don’t want to order this 0.090” thick sheet. Requires cutting to size.
Screen
Protector
1 | Supershieldz | N/A | iPhone SE and iPhone 5 Screen Protector
Amazon (https://www.amazon.com/gp/product/B00EOYMO66/)


Notes: Protection film for touchscreen. Needs to be cut to length. Most any PET screen protector film for iPhone 4, 4S, 5, 5s, or SE should work as they have the same screen width as the 3.5” LCD. Multiple vendors produce a similar product.

Item | Qty | Manufacturer | Mfr. P/N | Description | Suggested Vendor Link | Photo
Wrist Strap Lanyard | 1 | Hukado | N/A | Hukado Adjustable Hand Wrist Straps Lanyard, (6 Pack) 9.5 inches Nylon Lanyard | Amazon (https://www.amazon.com/gp/product/B07Q2QDG3Q)

Notes: Wrist Strap. This wrist strap works well, but other options are available in various lengths depending on your preference. O-Ring
Seals

4 ft The O-Ring Store

N50.103/
10

0.103" (2.62mm) Buna-N 50 O-Ring Cord Stock, 10' Piece, Black

O-Ring Store (https://www.theoringstore.com/store/index.php?main_page=product_info&cPath=117_527&products_id=53229)

Notes: O-Ring material for seals in main enclosure and LIDAR module. This 50 durometer material is preferred over more readily available 70 durometer since it is softer and can make a tighter seal. Must cut to length and glue ends (this vendor also sells O-ring glue in small quantities.) Other vendors sell similar material.

USB
Connection
Pins

OPTION 1

2 | Mill-Max | 0929-7 | Spring-loaded contacts – through- hole mount (Pogo pins)

Digikey (https://www.digikey.com/en/products/detail/mill-max-manufacturing-corp/0929-7-15-20-75-14-11-0/5722643)

Notes: Special pins to make connection to USB pads on underside of Teensy. This can be done with two pogo pins or with right angle pins and shorter header receptacles. Note that these pads have a 2 mm spacing instead of the usual 2.54 mm (0.1”) spacing. The pogo pin option is preferred.

USB
Connection
Pins

OPTION 2

1 | Harwin | M22-2531005 | Connector Header – through hole, right angle, 2mm | Digikey (https://www.digikey.com/en/products/detail/harwin-inc/M22-2531005/3728251)
1 | Samtec | SQT-102-01-L-S | Connector Receptacle – through hole, 2mm | Digikey (https://www.digikey.com/en/products/detail/samtec-inc/SQT-102-01-L-S/1108780)

Notes: Special pins to make connection to USB pads on underside of Teensy. This can be done with two pogo pins or with right angle pins and shorter header receptacles. Note that these pads have a 2 mm spacing instead of the usual 2.54 mm (0.1”) spacing.

Other Required Items:
PETG Filament for 3D Printing Caveatron SV Printed Circuit Board CR1220 Battery
Single row male headers
Single row female headers
Double row female headers 2x20 (for 40 pin LCD Connector) 6-32 x 1/2” Flat Head Screws (8x)
6-32 x 3/8” Pan Head Screws (4x)
6-32 x 9/16” Pan Head Screw (1x)
6-32 Nut (3x)
Adhesive-backed foam
Epoxy, sealant, and grease
Tape (Kapton or electrical)
Soldering supplies

Notes: For assembly and electrical interconnections between boards. Several sizes of standard hardware required. More information in assembly instructions.

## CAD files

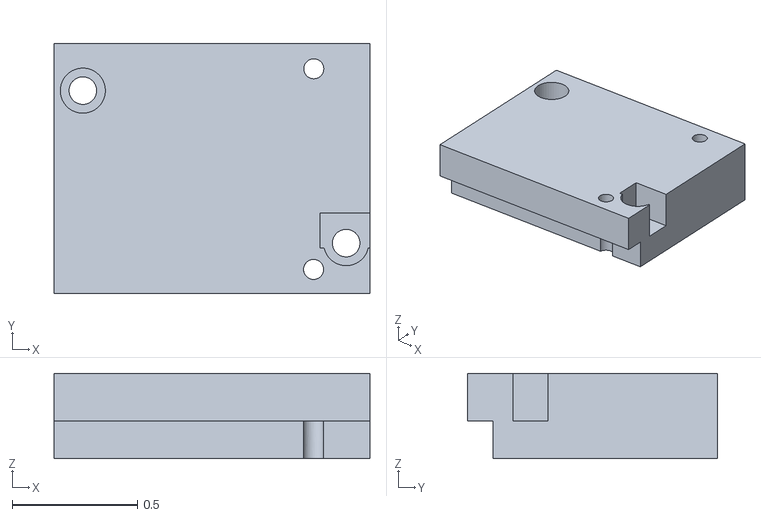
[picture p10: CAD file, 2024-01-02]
RevC/mechanical/GPS Bracket v2.stl
1.26 x 0.995 x 0.34

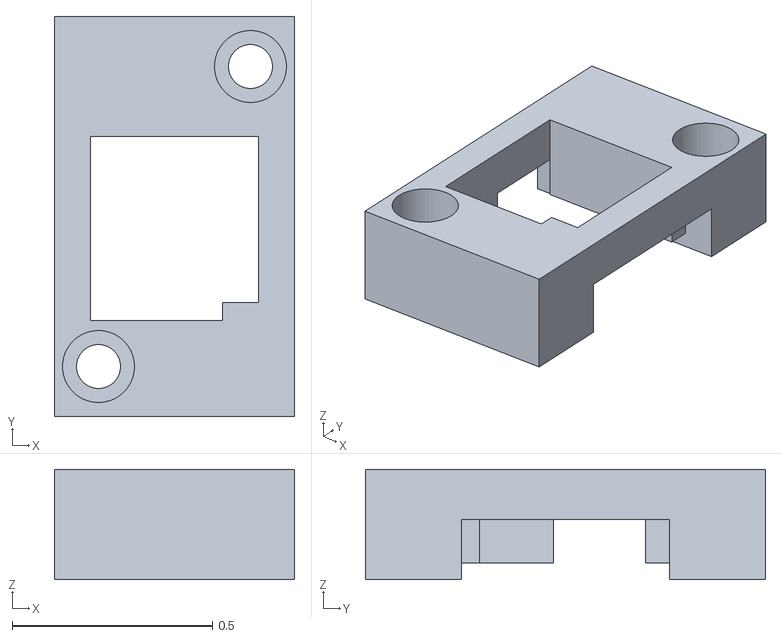
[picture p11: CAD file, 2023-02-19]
RevC/mechanical/RM3100 Cover_RevC v2.stl
0.6 x 1.00 x 0.275

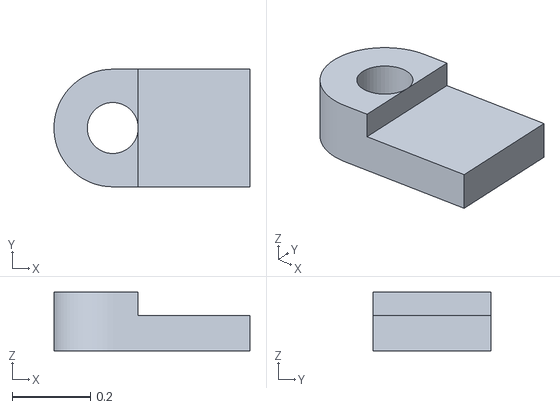
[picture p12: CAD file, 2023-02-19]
RevC/mechanical/LCD Clamp_RevC v3.stl
0.5 x 0.3 x 0.15

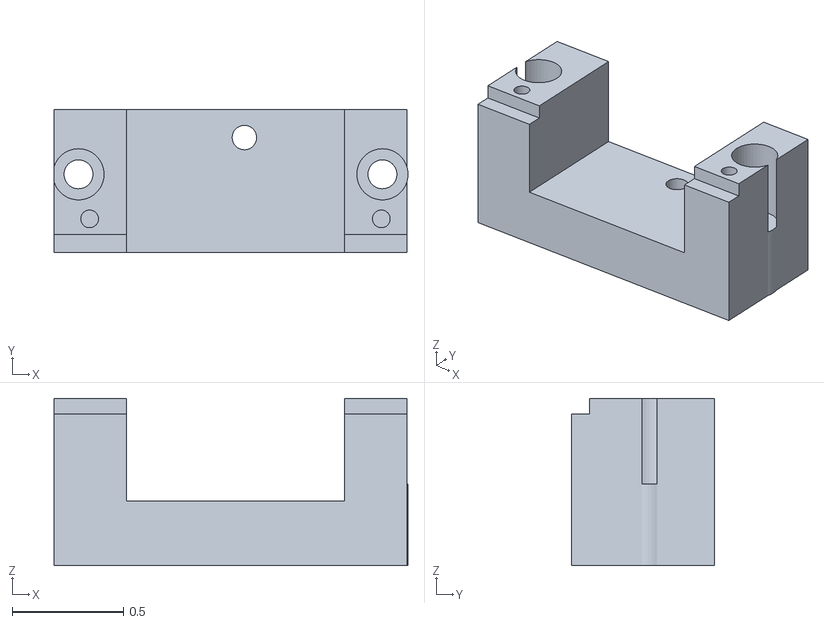
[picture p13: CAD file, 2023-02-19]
RevC/mechanical/LRF Bracket Base_RevC v1.stl
1.59 x 0.64 x 0.75

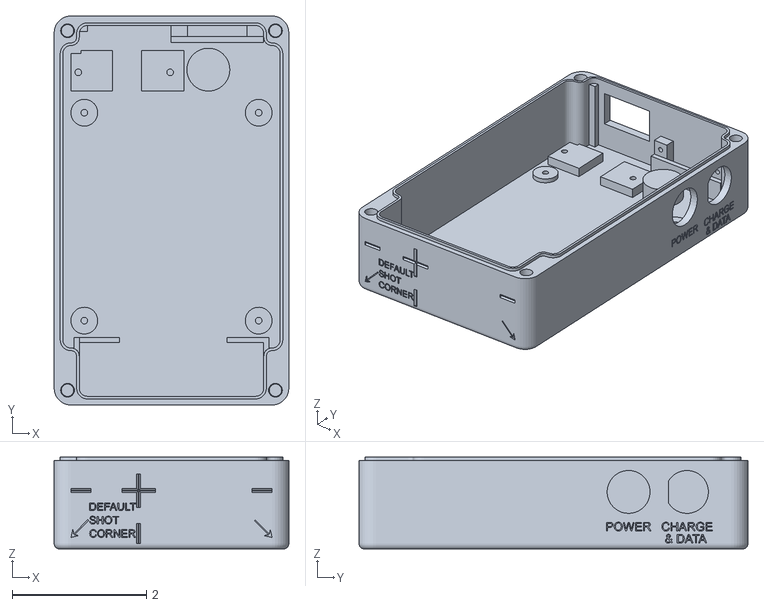
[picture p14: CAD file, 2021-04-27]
RevC/mechanical/Caveatron SV Enclosure Base v8.stl
3.50 x 5.80 x 1.37

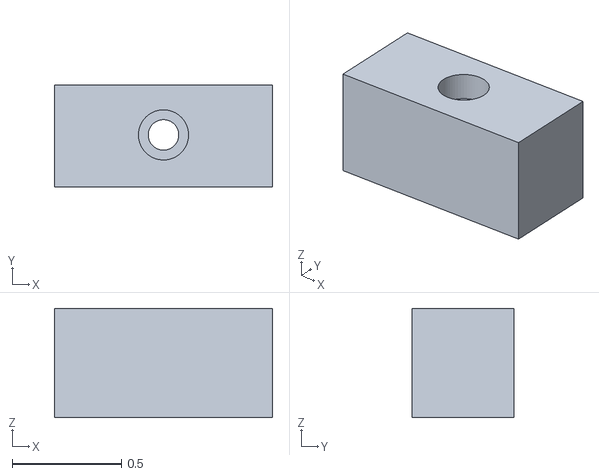
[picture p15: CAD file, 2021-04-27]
RevC/mechanical/Battery Clamp v1.stl
1.00 x 0.47 x 0.5

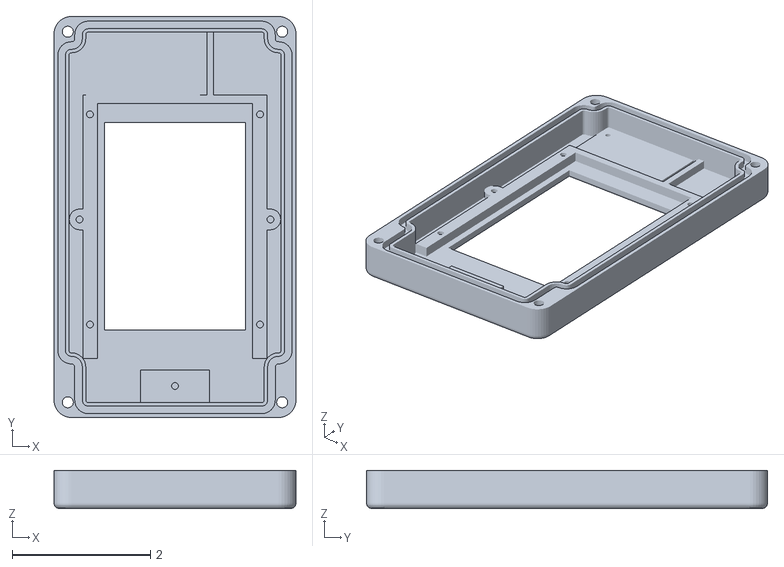
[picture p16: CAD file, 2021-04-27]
RevC/mechanical/Caveatron SV Enclosure Lid v9.stl
3.50 x 5.80 x 0.55

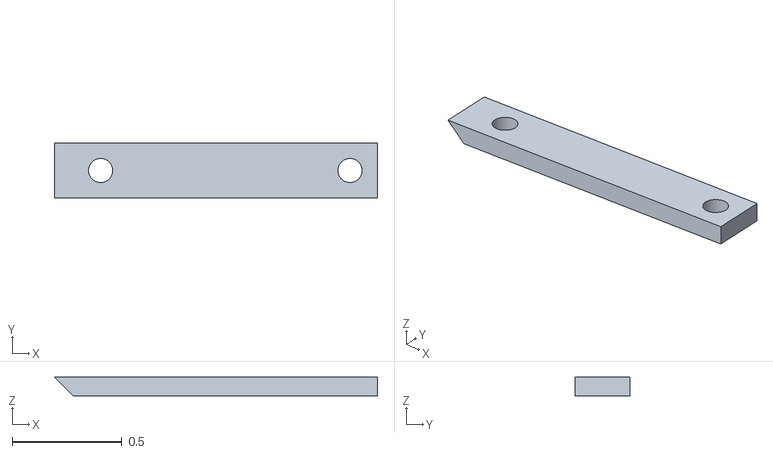
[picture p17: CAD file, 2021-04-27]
RevC/mechanical/Buzzer Clamp v2.stl
1.47 x 0.25 x 0.085

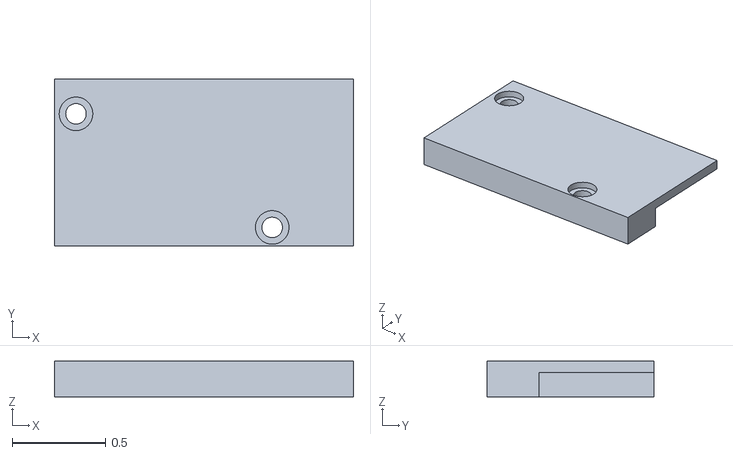
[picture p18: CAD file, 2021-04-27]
RevC/mechanical/Bluetooth Bracket v4.stl
1.60 x 0.895 x 0.19

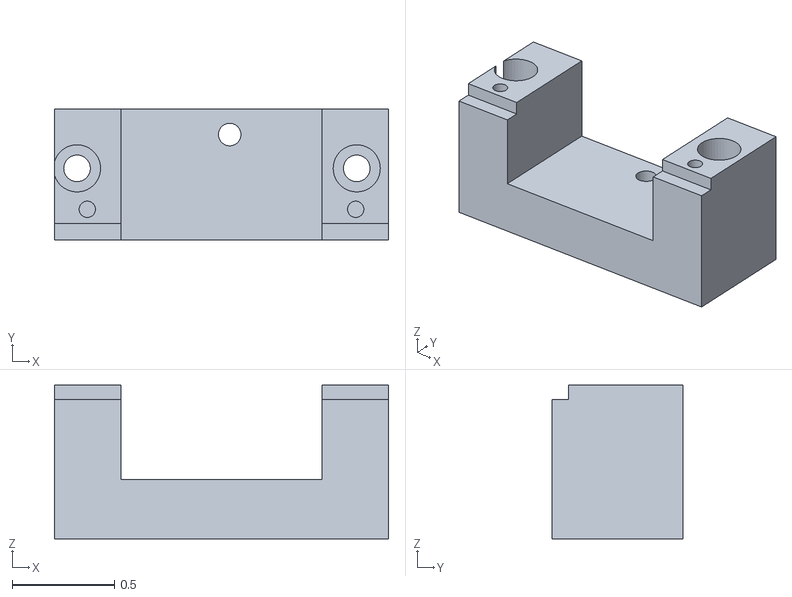
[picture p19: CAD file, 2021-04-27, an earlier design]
RevA/mechanical/LRF Bracket Base v2.stl
1.63 x 0.64 x 0.75

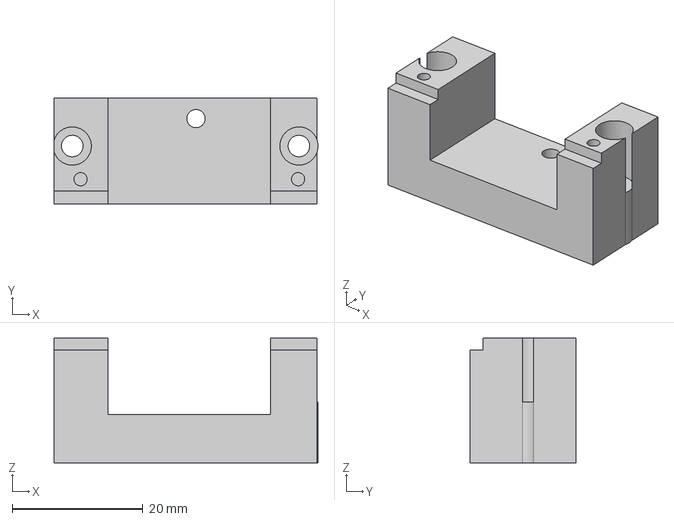
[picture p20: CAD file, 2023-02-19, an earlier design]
RevA/mechanical/STEP files/LRF Bracket Base_RevC v1.step
40.4 x 16.3 x 19.0 mm

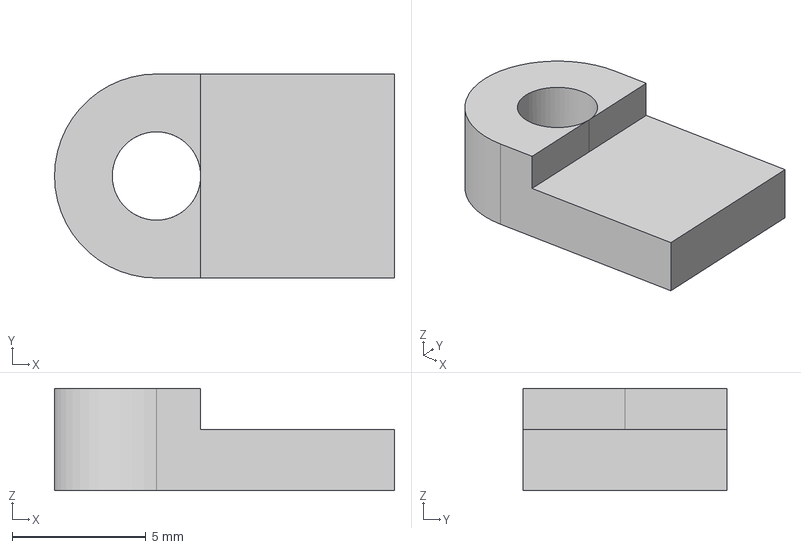
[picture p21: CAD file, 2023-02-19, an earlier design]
RevA/mechanical/STEP files/LCD Clamp_RevC v3.step
12.7 x 7.62 x 3.81 mm

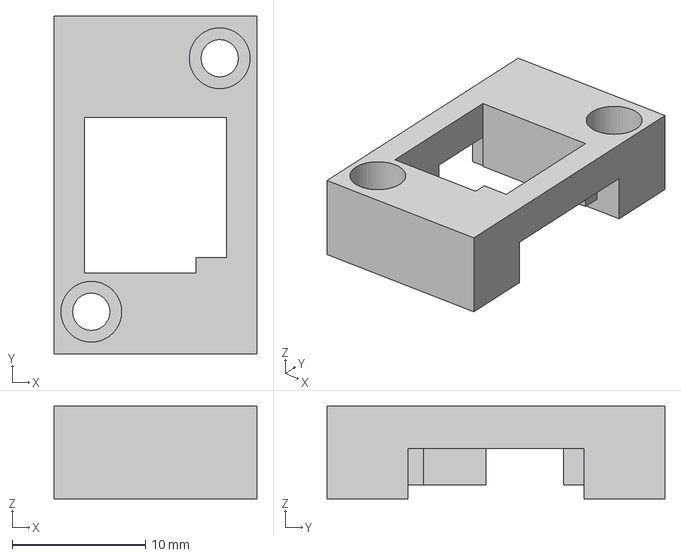
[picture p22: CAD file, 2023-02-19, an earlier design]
RevA/mechanical/STEP files/RM3100 Cover_RevC v2.step
15.2 x 25.4 x 6.98 mm

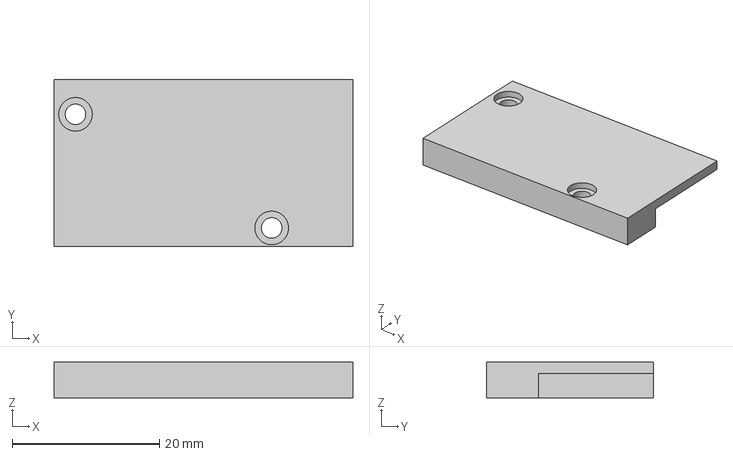
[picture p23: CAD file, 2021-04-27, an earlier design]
RevA/mechanical/STEP files/Bluetooth Bracket v4.step
40.6 x 22.7 x 4.83 mm

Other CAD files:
RevA/mechanical/STEP files/LCD Clamp v2.step
RevA/mechanical/STEP files/Buzzer Clamp v2.step
RevA/mechanical/STEP files/LRF Bracket Top v2.step
RevA/mechanical/STEP files/Battery Clamp v1.step
RevA/mechanical/LCD Clamp v2.stl
RevA/mechanical/LRF Bracket Top v2.stl
RevA/mechanical/STEP files/Caveatron SV Enclosure Base v8.step
RevA/mechanical/STEP files/Caveatron SV Enclosure Lid v9.step
RevA/mechanical/STEP files/LRF Bracket Base v3.step

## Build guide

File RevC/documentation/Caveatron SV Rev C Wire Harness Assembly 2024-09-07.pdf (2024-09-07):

## Caveatron SV Rev C - Wire Harness Assembly

Version: 2024-09-07

CAUTION: Do not pay attention to wire colors except where noted below. Pre-wired connectors are usually wired with arbitrary wire colors so will not be consistent. Be especially careful with two wire connectors to be sure you are not wiring it backwards (sometimes the black wire on these pre-wired connectors is in the positive position!)

### Connectors, Pin Conventions, and General Notes

These connectors are used in the wire harnesses and the pin number convention is shown below:
- JST XH 2.54 5-pin connectors are used on the Laser Rangefinder (LRF), the Power Switch, and the Bluetooth module.
- JST XH 2.54 2-pin connectors are used for USB Power, USB Data, the Piezo Buzzer, and the Battery. JST XH (2.54 mm)

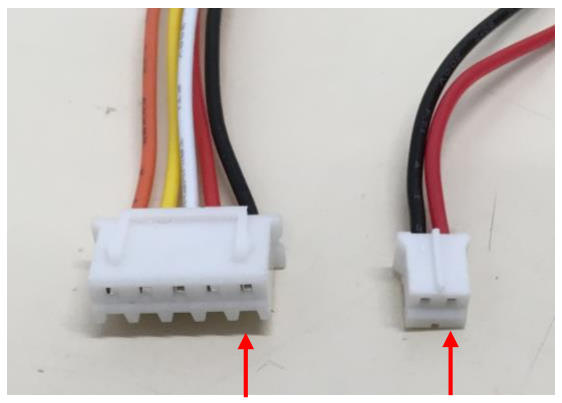
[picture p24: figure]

Pin 1 | Pin 1

The photos on the next page show examples of the wiring harnesses used in the Caveatron SV. It is highly recommended that heat shrink tubing be used on all solder interfaces and as strain relief on soldered pins. Kapton tape and/or small cable ties can be used for additional strain relief. Be extra careful when wiring the battery to avoid allowing the wires to touch.

Also note that using a coin cell for the Teensy RTC battery backup is no longer recommended due to the short battery life (45 days). Instead, use the RTC regulator retrofit modification described in the separate document entitled “RTC regulator retrofit” (found with the regular Rev C Caveatron documentation.)

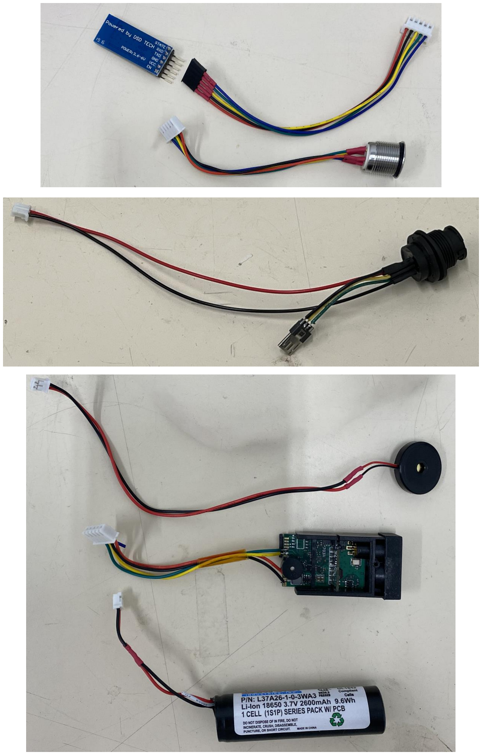
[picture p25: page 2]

### Laser Rangefinder

Pin on PCB Connector | Description
1 | +3.0 V
2 | GND
3 | RX on Teensy / TX on LRF
4 | TX on Teensy / RX on LRF
5 | -

Length of Wire Harness: 7.5” for V+/GND, 7.75” for RX/TX, 7” for Power On.

### JRT 40m LRF Module (Small)

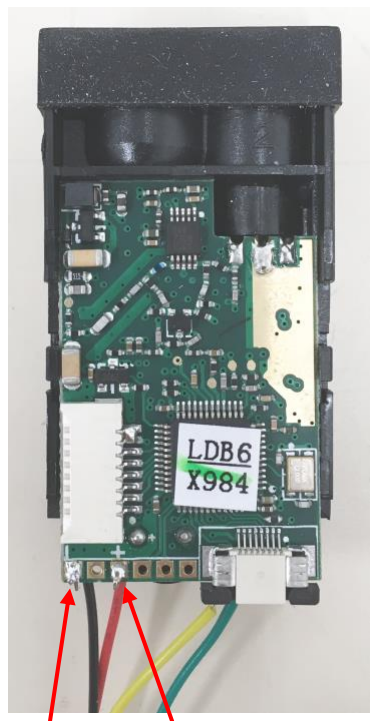
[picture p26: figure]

### Battery

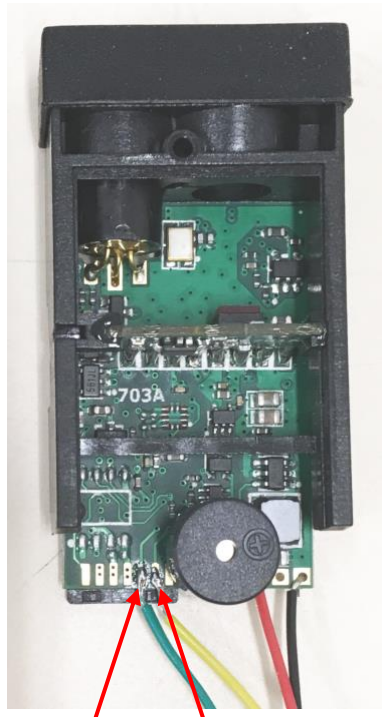
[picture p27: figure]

Pin on PCB Connector | Description | Battery Wire Color
1 | +V | Red
2 | GND | Black

Length of Wire Harness: 2.75”

GND | V+ | TX on LRF (RX on Teensy)
RX on LRF
(TX on Teensy)
Top View | Bottom View

### USB Connector

This Y-cable goes from the USB mini/micro external jack to a 2 pin JST and to a USB micro male connector.

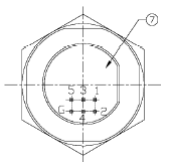
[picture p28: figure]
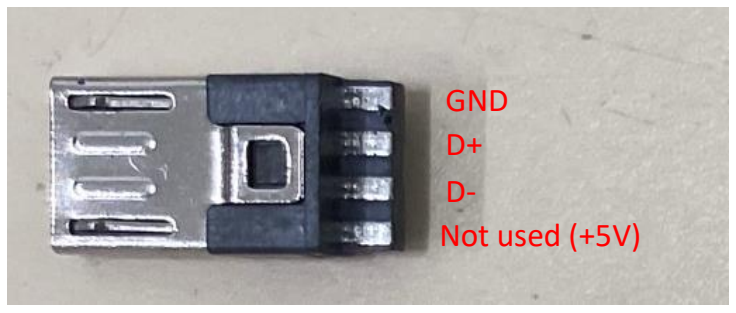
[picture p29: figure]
Not used (+5V); GND
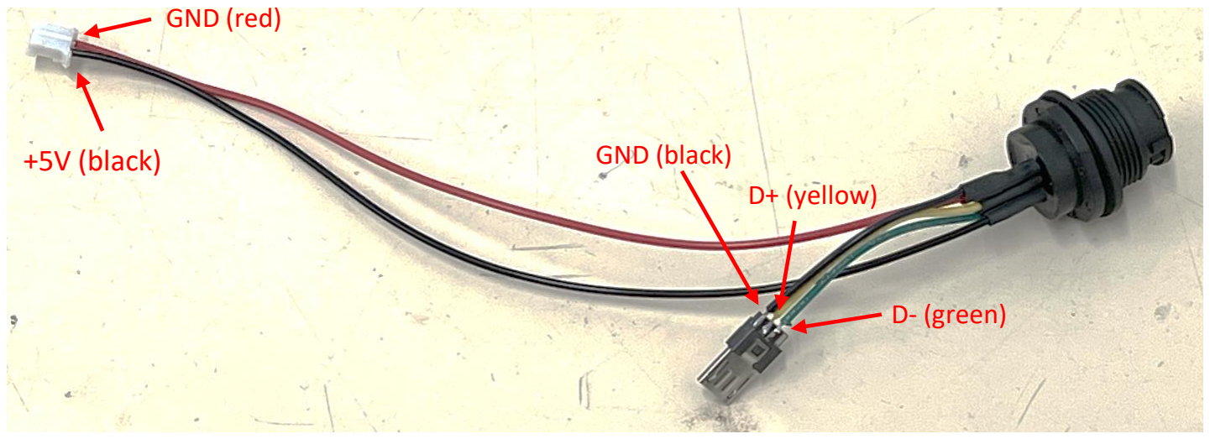
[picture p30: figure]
GND (red); +5V (black); GND (black); D+ (yellow); D- (green)

Pin on USB Connector | Description | Pin on 2-wire USB Power Connector | Pin on 2-wire USB Data Connector
1 | +5 V (VCC) | 1
2 | D- | | 2
3 | D+ | | 1
4 | -
5 | GND | 2
G | GND | 2

Length of USB Micro leg of Wire Harness: 2.25” Length of power leg leg of Wire Harness: 7.0”

### Piezo Buzzer

Pin on PCB Connector | Description | Piezo Buzzer Wire Color
1 | +V | Red
2 | GND | Black

Length of Wire Harness: 6.5”

### Power Switch

Pin on PCB Connector | Description
1 | +5 V (C+)
2 | Red LED Cathode
3 | Green LED Cathode
4 | Switch A
5 | Switch B
(Switch A and B do not have a polarity and can be reversed)

Length of Wire Harness: 2.5”

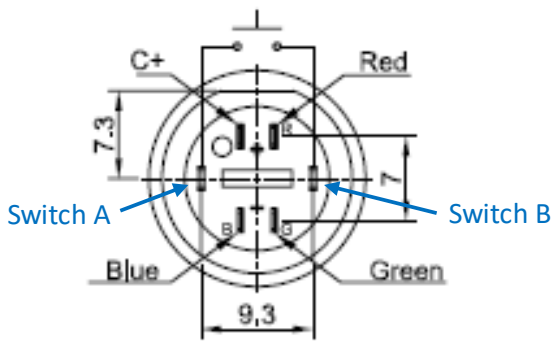
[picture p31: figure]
Switch A; Switch B

### GPS Module (optional)

Two wire harnesses are needed for this module. A 5-pin primary and a 2-pin battery backup.

Pin on PCB Connector | Description
1 | Enable
2 | +5V
3 | GND
4 | RX on Teensy / TX on GPS
5 | TX on Teensy / RX on GPS

Length of Wire Harnesses: 5.5”

### Bluetooth Module (optional)

Pin on PCB Connector | Description
1 | Enable (on HC-05 only)*
2 | +5V
3 | GND
4 | RX on Teensy / TX on Bluetooth
5 | TX on Teensy / RX on Bluetooth

* Note: The enable pin is only used with the HC-05 bluetooth module. On the HM-10, this pin is not wired.

Length of Wire Harness: 5.5”

Pin on PCB
Connector

Description

1 | VBAT
2 | GND (optional – GND also connects through other harness

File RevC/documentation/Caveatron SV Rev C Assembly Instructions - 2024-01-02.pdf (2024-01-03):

## Caveatron SV Rev C Assembly Instructions

### Version: 2024-01-02

### Overview

This document provides instructions on how to assemble the Caveatron SV – the non-LIDAR version focused on traditional sketch-based cave survey. This version has a 3D printed enclosure and a custom printed circuit board (PCB) and requires cutting one acrylic part and soldering items to the PCB including a few smaller surface-mount components. The Caveatron SV includes either an optional GPS module for marking entrances or surface features or an optional Bluetooth module that is planned be used in conjunction with the Android tablet-based sketch software, TopoDroid (but has not been implemented as this time.)

Some Tools Required:
- Band Saw (or other tool for cutting plastic)
- Soldering Iron
- Screw drivers
- Pliers
- Tweezers

Assembly Materials Required:
- Marine grade adhesive
- O-ring epoxy
- O-ring lubricant (synthetic grease)
- Soldering supplies including heat shrink tubing
- Adhesive-backed foam
- Tape (Kapton or electrical)

### Enclosure

3D Printed Parts
The enclosure parts are 3D printed. Detailed information about the parts and printing them can be found in the separate “Caveatron SV 3D Printed Parts Description” document. The material I used is PETG which is much more durable than PLA, but more flexible and easier to print than ABS. If the goal is to maximize durability, then ABS would probably be fine, but I would not recommend PLA.

There are 12 printed parts needed (11 unique parts) as summarized below and shown in the photo:

- Main Enclosure Base
- Main Enclosure Lid
- LRF Cradle Bracket
- LRF Clamp
- IMU Bracket
- RM3100 Bracket
- RM3100 Clamp
- LCD Clamp (2 pieces)
- Battery Clamp
- Buzzer Clamp
- (Optional) GPS Bracket or Bluetooth Clamp

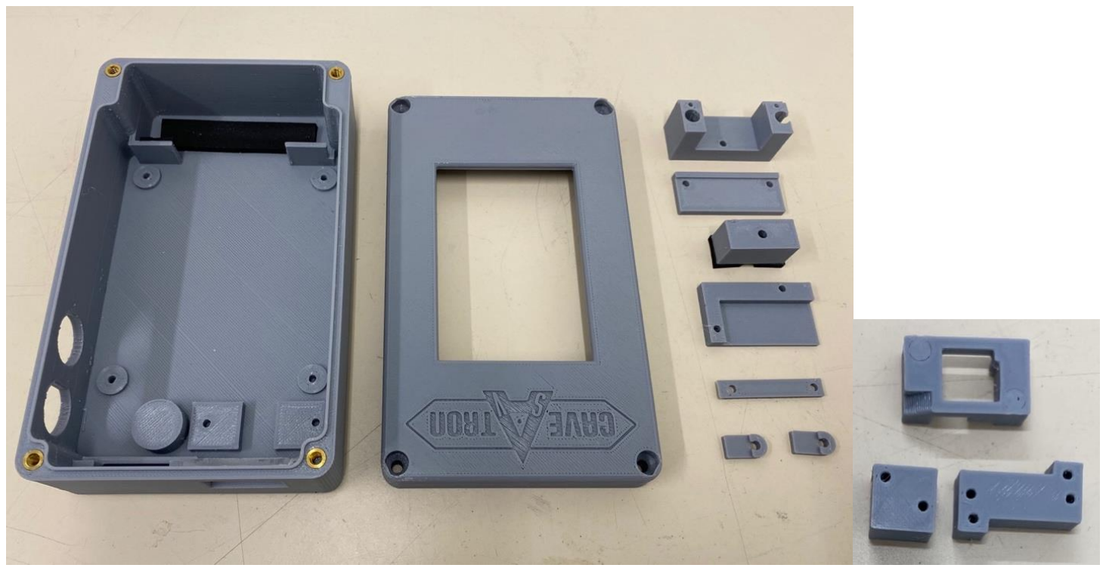
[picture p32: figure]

3D Printed Parts. Threaded inserts for attaching the lid are installed in the main enclosure base at left.

Preparing the Parts
After printing the parts and removing support material, a small amount of sanding with a fine grit sanding sponge or sandpaper may be desired to clean up the edges – especially on the main enclosure to give the edges a little more of a rounded edge for more comfort while holding it. There is sometimes residual stringing from the printing process that need to be removed.

Installing the Threaded Inserts
The parts have holes for either thread-rolling screws, for mounting smaller components, or for threaded inserts, where a more durable connection is required. Heat-set threaded inserts are installed using a soldering iron. Two sizes are used as indicated below:
- #6-32
- 4 in the Main Enclosure Base top side corners for attaching the lid
- ¼-20 (optional - for external mounting)
- 1 on the underside of the Main Enclosure Base

Before installing the inserts, have a matching screw ready to check that the insert if vertical. To install them, hand press them as far as you can into the hole and give them a few light taps with a tool. Press the soldering iron onto the top of the insert for a few moments to allow it to heat up the part and then start gently pressing and slightly wiggling the insert to encourage it to move deeper into the hole. Be careful not to the let the soldering iron slip and damage the 3D part surface. Keep pressing and wiggling until the insert is level with the top surface of the part as shown below. Remove the soldering iron and quickly thread in the matching screw a short distance and look to confirm that the screw sticks straight up from the surface. Be careful since the inserts are very hot! If it is angled by any significant amount, try to use the screw to straighten it out before the plastic cools and re-hardens. Otherwise leave in the screw and use the soldering iron to warm it back up to correct it (be careful to avoid getting burned).

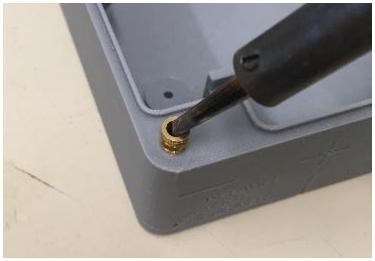
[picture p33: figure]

Use a large tip soldering iron to install the inserts. As shown In the photo at left, tilt the soldering iron along the edge of the insert or use a wide tip to be sure to not get the tip stuck inside the insert or it will pull out the insert once you have pressed it in. Be sure that the inserts are installed level with the surface. Use a matching screw to quickly confirm that the inserts are installed vertically and not tilted. If you are fast enough you can use them to correct any tilt before the plastic cools down. Be careful as the inserts are very hot!

Acrylic Window
There is one clear acrylic window that must be cut out and installed for the LRF window. After cutting it out, test the cut piece by placing it in position. Once you are satisfied with the fit, it is time to glue it into place. Use a marine grade or other waterproof adhesive – I suggest something like Flex Seal Flex Glue https://flexsealproducts.com/products/flex-glue. Place the epoxy on the inside walls of the enclosure window cutout. Put in just enough to get continuous coverage but not too much or it will ooze out when you insert the window. This is best done using a syringe to get a thin bead around the interior of the recess as described on p. 15 and 16. Use a glove to press the window into place so as not to get fingerprints on it and being careful that no epoxy gets on the center part of the window. Press it tightly for several minutes to allow the epoxy to set up and clamp it. Allow it to cure for 24 hours.

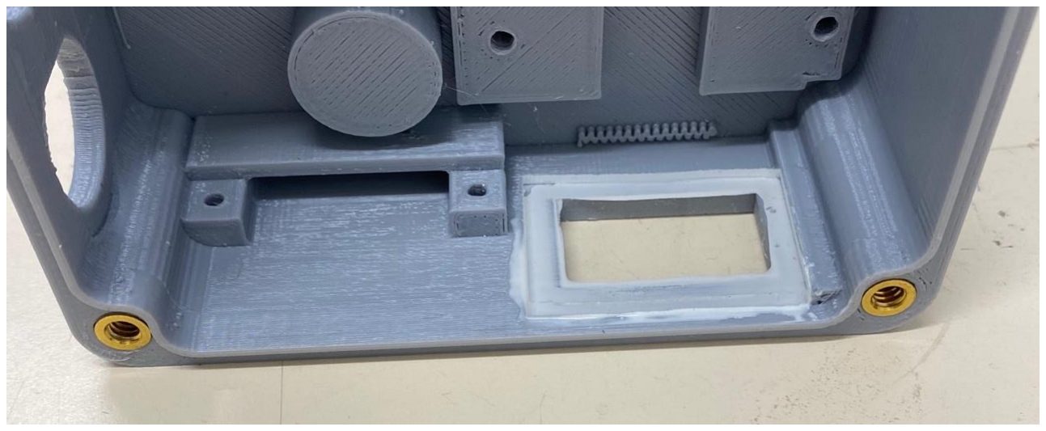
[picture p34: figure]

LRF Window: Place epoxy around the perimeter of the window opening. Using a glove, press the window into place being sure not to get any on the open part of the window.

O-Ring Gaskets
A custom O-ring gasket is needed for the lid. This is cut from gasket cord and glued on the cut ends into an O-ring using O-Ring epoxy (regular cyanoacrylate can be used as well). Cut to the following length:
- 15” (38 cm)

When epoxying the ends together, be sure to get an aligned joint. After the epoxy has cured, smear a bit of lubricant along the length so that it will go in more easily and improve the seal. Press the O-ring into the slot starting at one location and working around the perimeter. Work it in so that it is consistent and not sticking out or pressed too far in at any location.

### Wire Harnesses

Detailed instructions for preparing the wiring harnesses can be found in the separate “Wiring Harness Assembly” document. There are 7 wiring harnesses:

- Laser Rangefinder
- USB Power
- USB Data
- Power Switch
- Piezo Buzzer
- Battery
- Bluetooth (optional)

### Electronics

Some electronics modules are intended to be attached to the printed circuit board (PCB) by plugging them into a female header while others are to be directly soldered onto the board. All of the components will need male header pins soldered onto them as well, though for some components, only selected pin locations are populated. Also, not all pin locations on the PCB are used. This is described below.

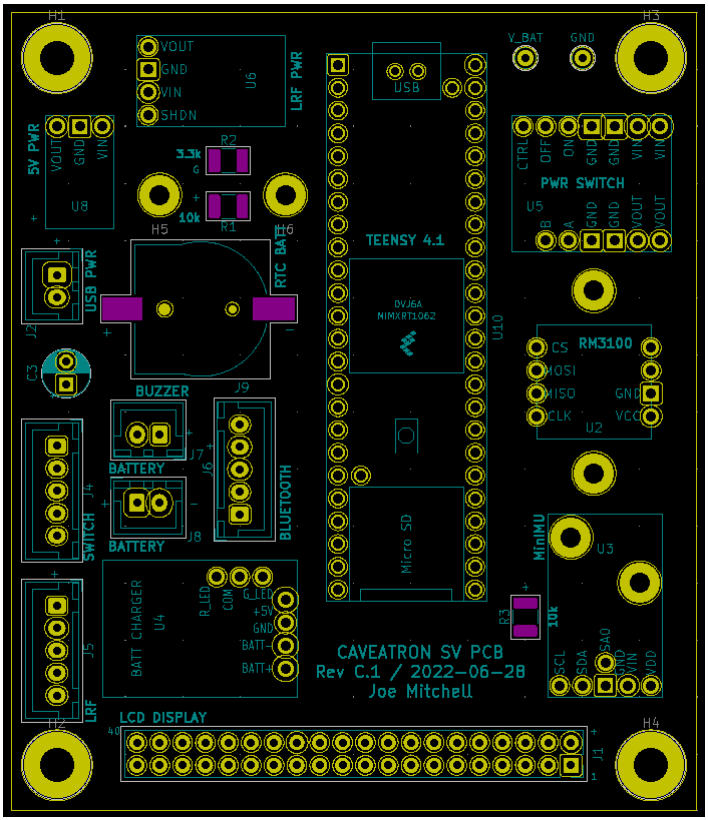
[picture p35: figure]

Schematic of Caveatron SV Rev C PCB

Teensy 4.1
The Teensy needs to be modified to add the Font/Graphics IC (SPI flash memory chip) and at least 1 header pin.

A Winbond SPI flash memory IC is used for the Font/Graphics IC and is soldered directly to pads on the backside of the Teensy board. There are two pad positions – be sure to use the slightly larger pad position further from the edge as indicated by the red arrow in the figure below. Before soldering, be sure the indicator dot on the SPI flash IC is aligned to the silkscreen dot on the Teensy board. Soldering an 8-SOIC package is best done by using tweezers to align the IC hold then press it down to the board. Get a small drop of solder on a small soldering iron tip and apply it to one pin while continuing to hold it down and brush it outward along the pad away from the IC to get a smooth line of solder from the pin to the pad. Once one pin is attached, double check the alignment, then solder each of the other pins. A picture of the SPI flash attached to the board is shown below.

If you ordered it with pins pre-soldered, you need to add one additional male header pin at the Vb (1x1) position for the real-time clock (RTC) battery. If you ordered it without pins, then you will also need to solder both full edge rows with a 1x24 set of pins. On the PCB, two 1x24 rows of female header sockets are soldered to the board along with one 1x1 female header sockets under Vb.

For the USB connection to the Teensy board, the USB Data/Power wiring harness that you create has a USB micro connector soldered to one leg of wires that you simply plug into the Teensy.

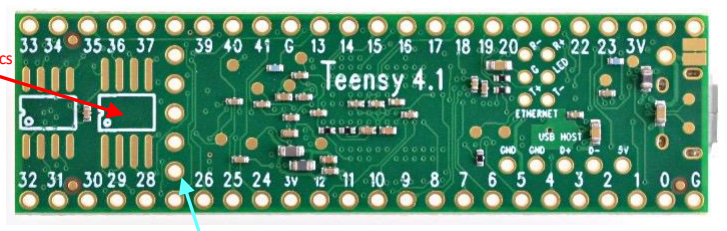
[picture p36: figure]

Teensy 4.1 Board. In addition to all of the 24 pin along both sides, the pin marked with the blue arrow must be populated with a male header. The Graphics IC (SPI flash memory module) is soldered on the pad indicated with the red arrow at left and shown after soldering in the photo at right.

Voltage Regulators (5V)
All pins on this board are populated with a 1x3 male header and is soldered directly to the PCB at the location marked 5V PWR. Pay special attention to be sure to get its orientation correct.

Voltage Regulators (LRF)
All pins on this board are populated with a 1x4 male header and is soldered directly to the PCB at the location marked LRF PWR.

MinIMU
All 5 pins along one edge of the board are populated with a 1x5 male header and it is plugged into a 1x5 female header socket that is soldered to the PCB at the location marked ”MinIMU”. (The inset SA0 pin is not used.) This component is additionally attached to the PCB with the IMU bracket. Since the positioning

older raphics
here of this component is more important than the others (to get the compass orientation correct), the following procedure should be followed. First solder the female headers to the PCB. Insert the male headers into the socket without soldering them to the IMU. Attach the IMU board to the IMU bracket with one 2-28 x 1/4” long thread rolling screw. Place the IMU and bracket onto the main PCB (with the tops of the pins through the IMU board pin holes) and attach the IMU bracket to the PCB with two more 2-28 x 1/4” screws from the underside. Finally, solder the pins to the IMU board.

A location is provided next to the IMU pins on the PCB to solder a 10K surface mount resistor on the power inputs for the IMU (R5). This is highly recommended since the resistor prevents a problem where the IMU does not power up properly if the Caveatron is turned back on within a few seconds after being turned off.

Location of resistor for IMU module.

Power Switch Board
For this board, solder a 1x6 male headers to one side and a 1x7 male header to the other side. This component is soldered directly to the main PCB at the location marked PWR SWITCH.

Battery Monitor Resistors
Two surface mount resistors are soldered to the two indicated pads to serve as the battery monitor. Note that the two resistors have different values so be sure to install the correct one on the correct pads.

Location of battery monitor resistors and test point for calibration.

3.3k 1206
resistor

10k 1206
resistor

Battery
calibration
test point

RM3100 Magnetometer
All four pins along one edge (CS, MOSI, MISO, CLK) have a 1x4 male header attached while on the other side, a 1x2 header is used for only the GND and VCC pins. On the Caveatron SV PCB, the equivalent female headers are used. 4.2 mm short female headers are used here since the RM3100 has some tall components. The RM3100 also needs to be aligned to the main PCB as best as possible. One method is to place the female headers in a breadboard. Then cut the length of the male header pins so that they fully fit into the female headers. Insert them into the female headers, then press the RM3100 board in between the pins. Now with it resting in between the headers, solder the male headers to the RM3100. Now, with the female headers still attached to the male headers, place it on the RM3100 base bracket. Attach the RM3100 clamp on top of the bracket base using two 2-28 x 0.25” thread rolling screws. Now place the assembly onto the Caveatron SV P B at the location marked “RM3100” and insert the 2-28 x 0.25” thread rolling attachment screws from the rear. Do not fully tighten them yet. Attempt to align the assembly as square to the Caveatron SV PCB as possible, then tighten the attachment screws. Finally solder the female header pins to the Caveatron SV PCB from the rear.

Attachment of the RM3100 bracket. Be sure the 4 pins are to the left.

Other Parts & Connectors
Due to the short life of coin cells to power the Teensy RTC battery (about 45 days), it is recommended that you perform the RTC regulator retrofit modification instead of installing the coin cell battery holder. Instructions can be found with the regular Caveatron RevC documentation as a separate document entitled “RT regulator retrofit”. f you want to use a coin cell battery, the holder is soldered directly to the PCB in the location marked RTC BATT onto the surface mount pads. The plastic pins in the base of the battery holder align to the holes in PCB to hold it in place while soldering it.

A 2x20 female header socket is soldered to the PCB at the location marked LCD DISPLAY.

Three 5-pin JST connector sockets are soldered at the locations marked LRF (J5), SWITCH (J4), and (optionally) BLUETOOTH (J9). Four 2-pin JST connector socket are soldered at the locations marked BATTERY (J8), BUZZER (J7), USB DATA (J3), and USB PWR (J2). Be sure to the note the JST socket key orientation as shown on the PCB silkscreen to install them correctly.

Li-Ion Charger Module
The component must have a small modification preformed before installation or it will not function. The two indicated pins in the illustration below must be shorted together either with a solder bridge or soldering a 0 ohm surface mount resistor.

The charger board has 7 pins attached, four on the short side and three along the long side. It is then soldered directly to the PCB.

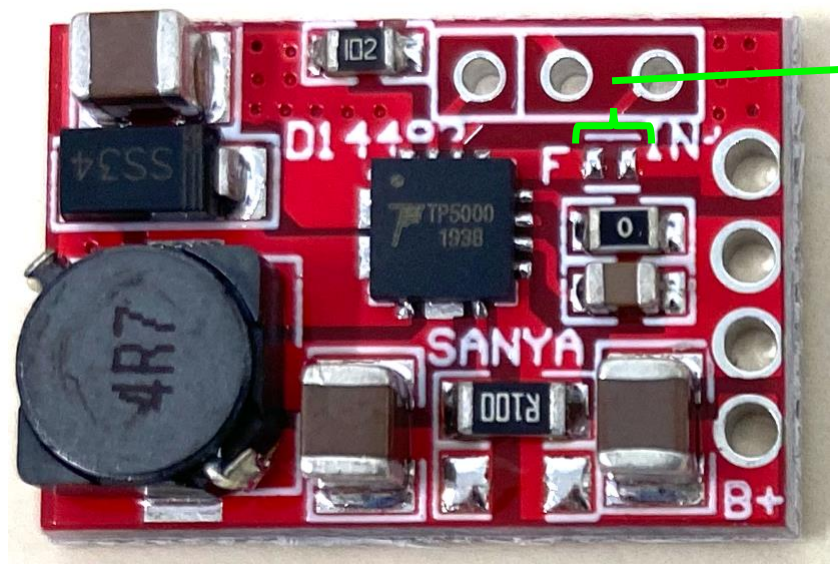
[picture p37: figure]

Li-ion Charger Module. The two pads indicated must be shorted together with a solder bridge or a 0-ohm resistor for it to function.

### Set the LRF Regulator Voltage

Before attaching the LRF, the output voltage of the adjustable regulator that powers the LRF needs to be set. Assuming you have not yet loaded any code onto the Teensy, you should be able to do this by plugging in the battery and connecting a voltmeter to the two most interior pins on the LRF JRT connector (J2) -the plus voltage pin (marked on the P B with a “+“, right next to the J2 label) and the minus pin right next to it. Press the small button on the Power Switch Board to turn the system on or off. Use a small screwdriver to adjust the pot on the voltage regulator until the voltage reads 3.0 volts.

Short across
these pads

To set the LRF regulator
voltage, measure across
these two pins.

+

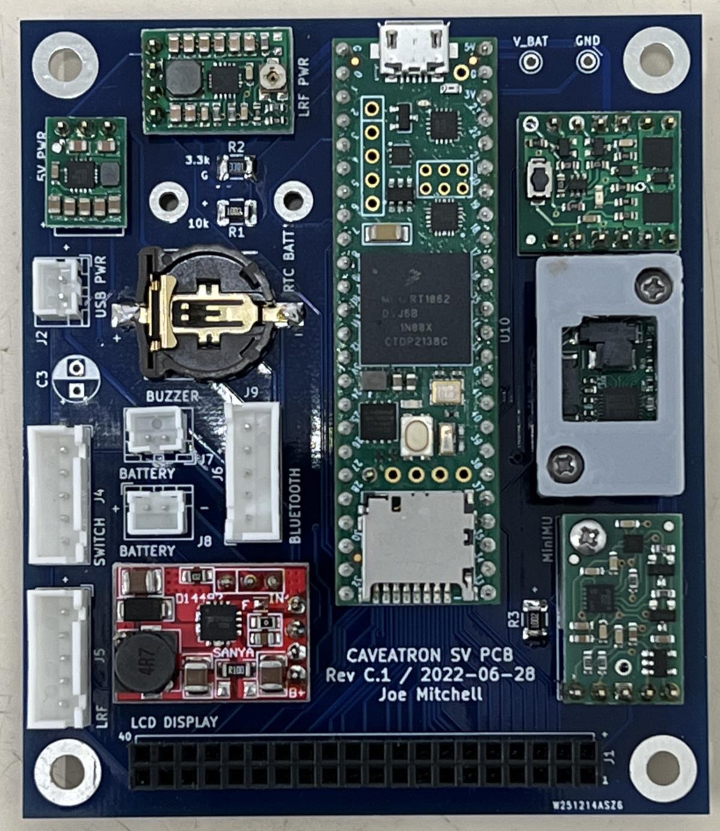
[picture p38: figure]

PCB with all components installed (not including the new RTC regulator retrofit).

### Main Enclosure Base Assembly

General note: When installing the thread rolling screws, it can be helpful to start the holes a little bit with the screw first before trying to install the part.

Circuit Board
Before installing the PCB, trim off the extra pin lengths on the underside of the PCB being sure none stick down further than the height of the support points in the enclosure base. The main PCB is installed using four 4-20 x ¼” thread rolling screws (one in each corner). You will need washers to prevent the screws from bottoming out in the holes which had to be shallow to avoid going too deep. Be sure that it is square to the enclosure by inserting each screw part way and then pressing back on the board from the front so that it is not skewed with respect to the walls.

Buzzer
The piezoelectric buzzer is installed into the slot along the front wall of the enclosure. The buzzer opening faces outward toward the enclosure wall. Be sure the wires come out toward the top right of the enclosure as shown. Press it into the slot and then install the buzzer clamp. Use two 2-28 x ¼” thread rolling screws to attach it. If the piezo buzzer slides out too easily, you might need to add a piece of tape to ensure it stays in place. The end with the slight inset cutout around the hole goes toward the LRF window. Route the wires right along the front of the PCB behind the LRF mount so they can slightly slide under the corner of the PCB to hold them in place as shown in the picture on the next page.

Insert the piezo buzzer into the slot (left) and then install the bracket (right).

USB Connector
The USB connector is inserted from the inside of the enclosure. It is keyed so it can only be inserted one way. Take the nut off first and be sure the gasket is in place on the connector. When installing it, be sure the piezo buzzer wires are not getting caught by the connector. After sliding the connector into the enclosure hole, install the USB connector cover by sliding it over the threaded part of the connector from the outside. Be sure to position it, so the connecting piece is toward the bottom front as shown. Screw on the nut and tighten it down. Route the longer power wires in front of the LRF mount under the LRF window as shown in the photo on the next page. The USB Micro-connector part of the cable is plugged directly into the Teensy 4.1.

Power Switch
The power switch is inserted from the outside of the enclosure. Be sure the rubber gasket that comes with it is placed on the switch body before installing it. Once in place, slide the nut over the cable and thread it onto the rear of the switch and tighten it into place. This wire harness goes across the top of the PCB to its connector as shown in the picture below.

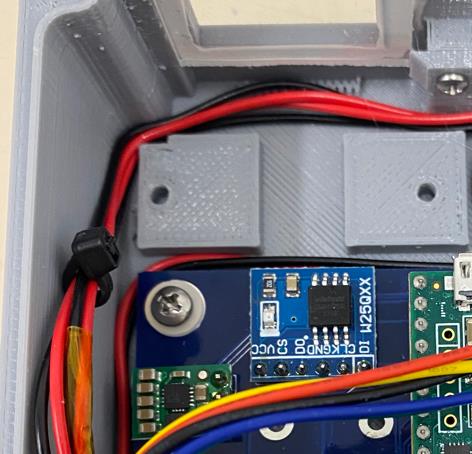
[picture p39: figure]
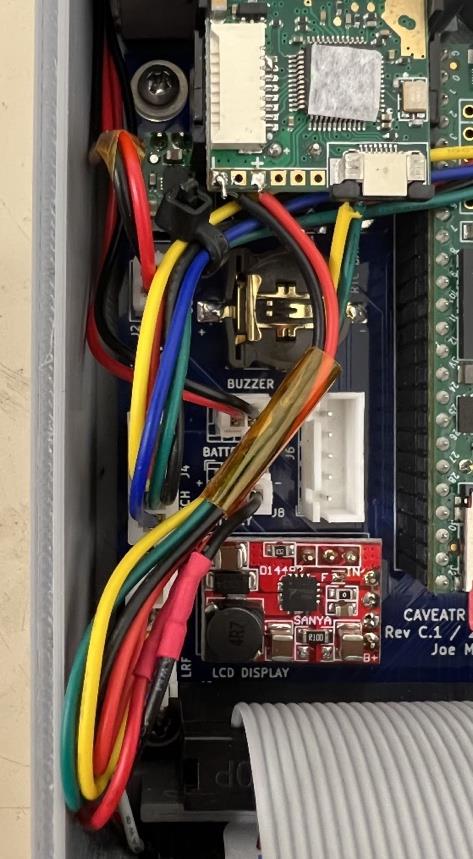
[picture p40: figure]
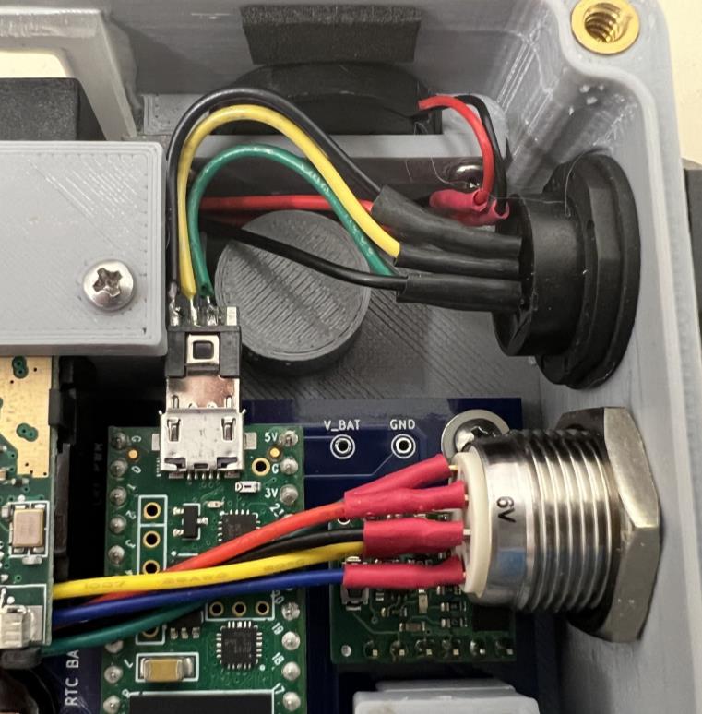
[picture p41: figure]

Installation and wire routing of the power switch, USB connector, and buzzer. (The photo at upper left is from Rev A but shows the routing of the buzzer and USB power wires.)

Laser Rangefinder
The LRF is installed in a cradle bracket that is in turn installed into the main enclosure base. When installing be sure to try to get all the parts as square to the enclosure as possible. The first step is to attach the bracket to the LRF. Look for a small hole in the front center of the LRF on one side as indicated by the arrow in the picture below. The cradle bracket has a countersunk screw hole which is aligned with the LRF and a 2-28 x ¼” thread rolling screw is used to attach it. Flip the cradle bracket over and align the two large holes with the holes on the LRF mount (visible in the picture on the previous page). Attach it with two 4-20 x ½” thread rolling screws. Finally, install the clamp on top of the cradle bracket as indicated in the photo below with two 2-28 x ¼” screws.

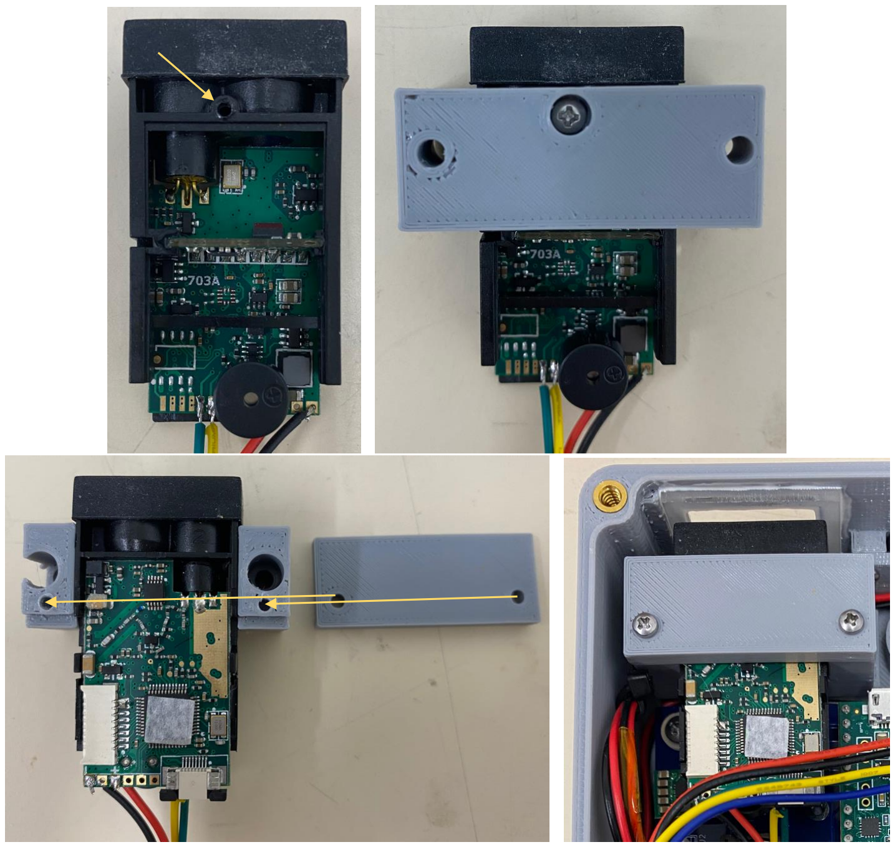
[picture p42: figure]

Installing the LRF. Attach the LRF to the bracket cradle (upper right) from the underside with a screw into the hole indicated (upper left), To install it in the enclosure, two 4-20 screws will go into the two large holes (lower left) and finally, the clamp will attach on top in the two small holes as indicated (lower left). The fully installed LRF is shown (lower right).

Battery
The battery goes in the large slot in the rear of the enclosure. To be sure it is tightly held and cannot slide around, a piece of adhesive backed foam is placed along the bottom of the battery slot. You may also need a piece of foam on one or both of the vertical parts depending on the battery’s fit. Orient the battery and insert it so that the wire harness goesinto the slit on the left front corner of the battery slot (as viewed from the rear of the enclosure). The battery will be fully secured by a bracket installed in the lid.

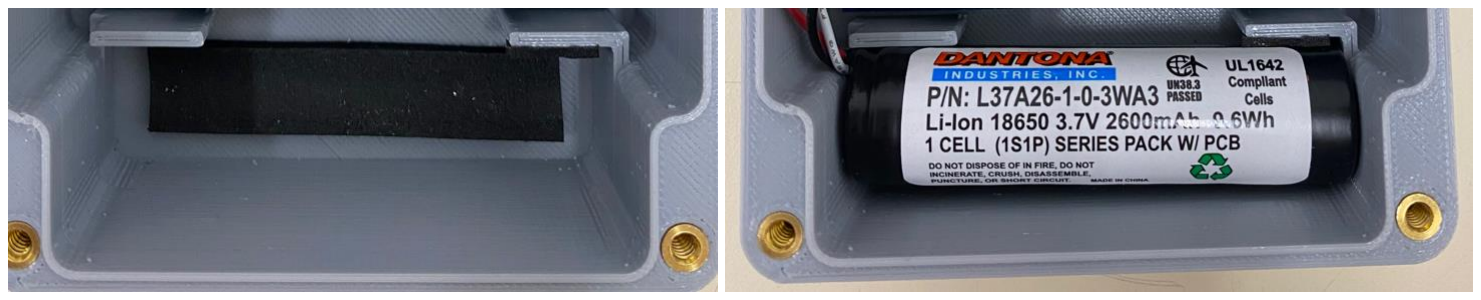
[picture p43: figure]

Foam adhesive backed pads to hold the battery (left) and the battery installed (right). This battery needed an additional piece of foam installed on the right-hand vertical piece.

Complete the enclosure base by installing the CR1220 battery into the coin cell battery holder. Plug in all connectors except for the battery which will be plugged in during final assembly. Be sure all wires are routed and reasonably secured.

Main enclosure base with everything installed.

### Main Enclosure Lid Assembly

Touchscreen LCD Display
The touchscreen LCD display goes in the lid of the Main Enclosure and connects to the main PCB by a 40-pin ribbon cable. Start by installing the screen protector which must be cut to size. The screen protector in the Bill of Materials is the correct width and only needs to be cut to the follow length:

creen Protector Length: 3 5/16”

Now remove the protective film on the display. Be careful not to touch the display or get any dirt particles on the display until you get the screen protector installed. For the screen protector, peel the cover film off of screen side, being sure not to touch or get any dirt particles on the exposed part of the protector. Install the protector, lining it up with the bottom end of the LCD (the end opposite the pins). Be sure to line it up with the actual top end of the display module (covering the white frame part) which is slightly beyond the end of the actual screen – this gives it a bit more coverage for the silicone to seal to it. Slowly lower the protector across the length of the display, keeping it aligned to the edges and not getting bubbles in the middle of the screen. Once on, smooth out the edges and then peel off the top covering on the protector and smooth out again if you need to.

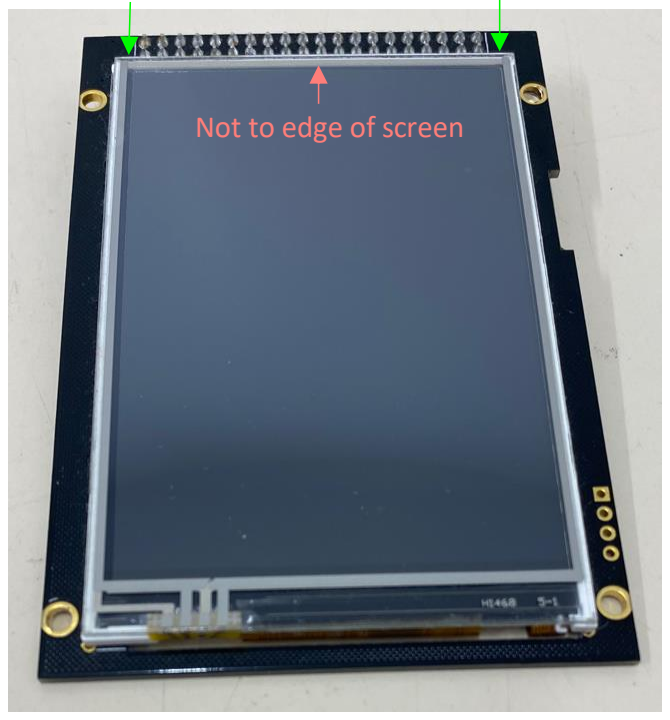
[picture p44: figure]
Not to edge of screen
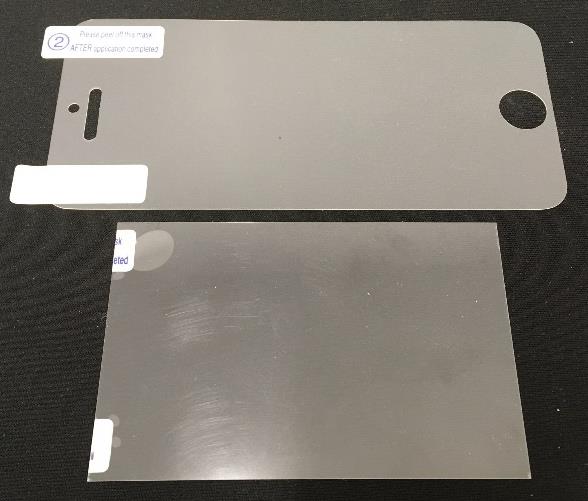
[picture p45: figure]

Preparing the Touchscreen Display. Cutting the screen protector to length (center with cut piece on the bottom) and place it on the screen (right). Be sure that the top of the protector is aligned with the white frame that is surrounds the display.

Before installing the screen, check the fit. Place it in the cutout as shown and be sure the screw holes line up. For best fit, slide it as far toward the front as possible (the end with the slot for the LIDAR module cable). When viewed from the top, you should not see any of the white frame of the display module, as shown below. Pull out the display and prepare to place silicone or epoxy sealant around the display
perimeter. | A | syringe | is | recommended | (I | use | these | 18 | gauge | needles:
www.amazon.com/gp/product/B07Z7MLFCZ) but you could use a toothpick or other method – just be

Align to top edge of white frame sure to get a thin, smooth bead all the way around the edge so that you get continuous coverage as shown. Don’t put on too thick of a bead or it will ooze out from under the screen edges when you screw it down in the next step.

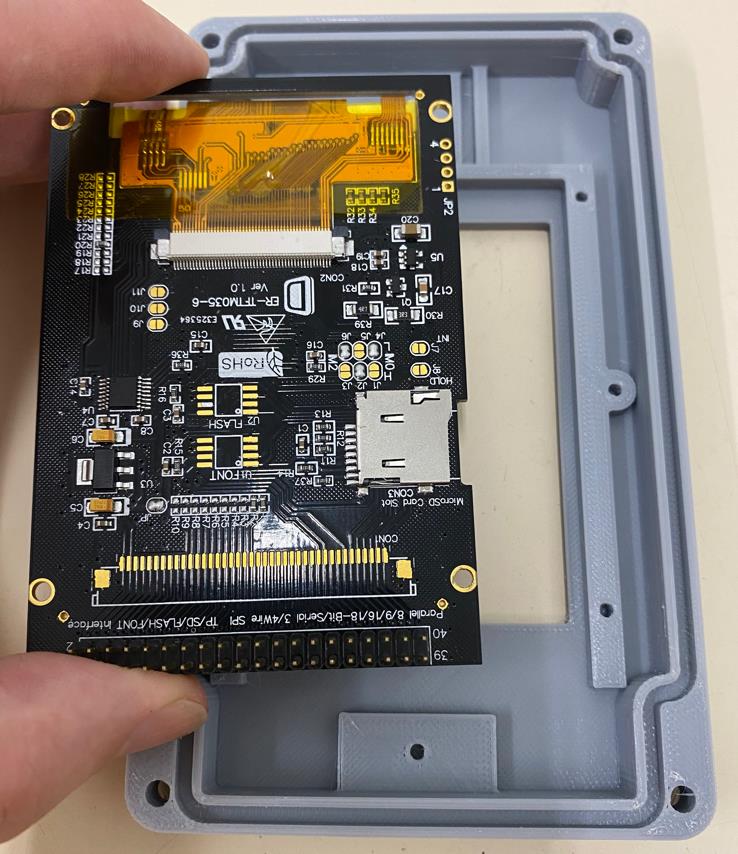
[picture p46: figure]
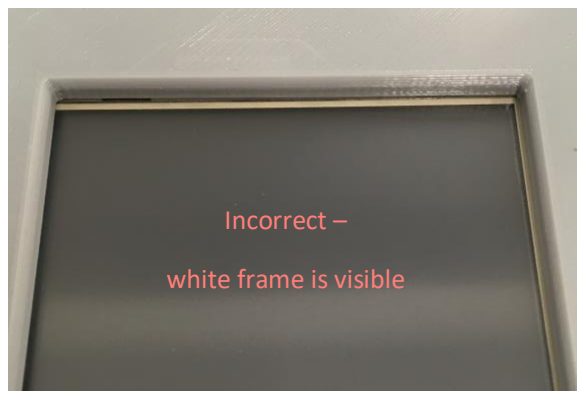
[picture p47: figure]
Incorrect –; white frame is visible
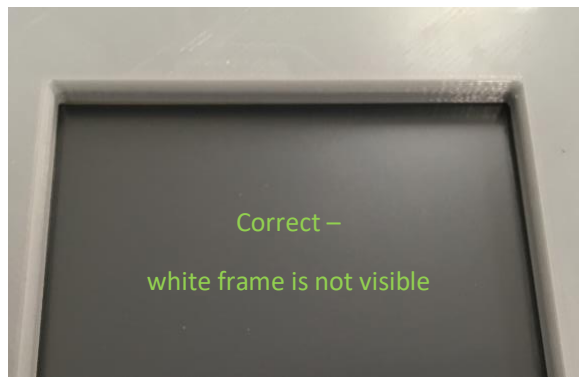
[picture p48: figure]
Correct –; white frame is not visible

Positioning the touchscreen module – from the back when inserted into the cutout (left) and positioning with the white frame not visible from the front – incorrect (top right) or correct (bottom right).

Once the sealant bead is applied, line up the display at the front end so that you
can tilt and press it down at the right spot in the cutout in a single movement (if
you have to slide it, you might end up smearing silicone onto the visible part of the screen). Use four 4-20 x ¼” thread rolling screws – one in each corner to secure it. Note that the holes in the LCD module are a little bit small and you will need to use a little bit of force to get the screws to go through. tart, but don’t tighten these down until you have all screws started. Finish tightening them. Now insert two more 4-20 x ¼” screws into the touchscreen display clamps, as shown, so that the lip on the clip will go over the display module PCB when inserted. Install and tighten the screws. Check the topside of the screen and clean up any excess sealant. Allow the sealant to cure.

LCD clamp screw
orientation

Add a silicone or epoxy sealant bead around the inside of the display cutout in the main enclosure lid (left). The screen installed from the backside (right) with screws and the clamps. Be sure not to put on too much sealant so it does not ooze out onto the screen and clean up any that does.

Battery Clamp
The battery clamp installs on the raised section right behind the LRF module using a single 4-20 x ½” thread rolling screw. Add pieces of adhesive backed foam as shown which will press down on the battery.

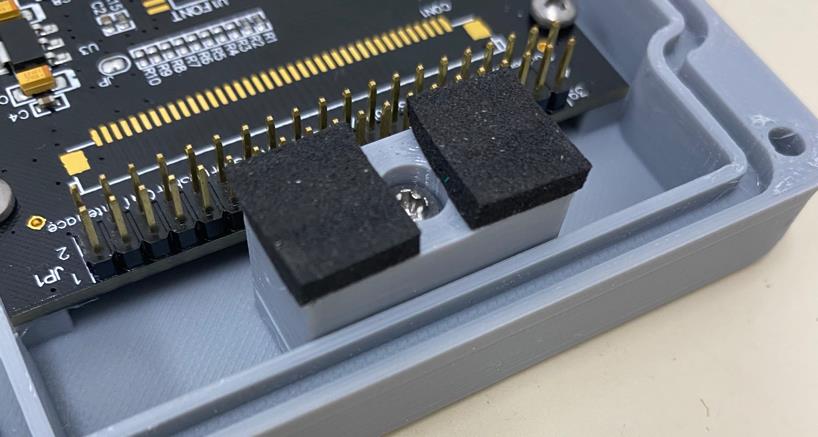
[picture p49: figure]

Battery clamp installed with adhesive backed foam added.

GPS Module (Optional – excludes use of Bluetooth module)
The Adafruit Ultimate GPS module is mounted on the underside of the front of the lid as shown in the photo below left. Due to the limited space, the wire harness must be soldered directly to the GPS module before installing. Be sure the wires attach on the side where the electronics are located. This connector plugs into the JRF socket on the main P B marked “Bluetooth”. The GPS bracket (shown in blue) is mounted first using two 2-28 x ¼” thread rolling screws in the holes in the lid indicated by the arrows in the photo in the Bluetooth module section below. Next, mount the GPS module upside down so the flat side is up using two 2-28 x ¼” thread rolling screws. Finally, if you want to keep the clock in the GPS module active (for faster satellite acquisition), run a wire between the backup battery pad on the module and the pad for Teensy RTC battery backup. On the GPS module, be sure to solder it to the smaller square pad, not the large round pads (with are ground). The pad closer to the front of the module is recommended as the rear one can interfere with an LRF mounting screw. The photo below right shows the connection to a Rev C board containing the RTC regulator retrofit with the attachment point for the wire indicated by the arrow (that allows it to be powered from the main battery instead of a short-life coin cell).

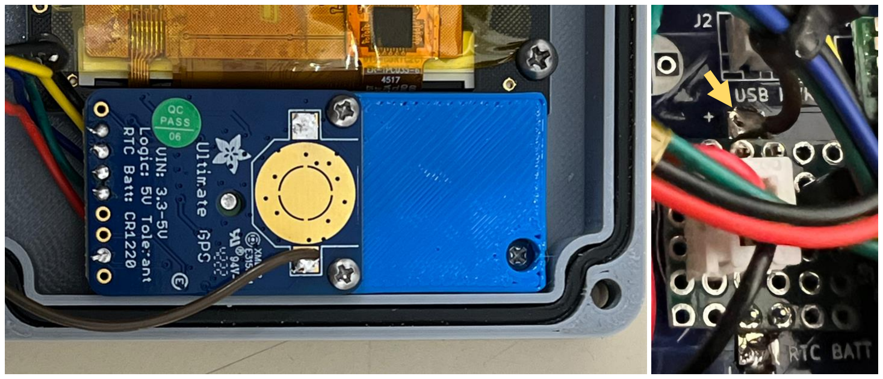
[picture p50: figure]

(Left) GPS module mounted on the inside of the front of the lid using the GPS bracket (in blue). Note that the electronics and 5 main wires for the wire harness are connected to the underside. These are +5V power, GND, RX, TX, and enable. This harness plugs into the “Bluetooth” JRT socket on the PCB. The GPS clock backup wire (brown) solders directly to the backup battery +power pad. (Right) The other end of the GPS clock backup wire attaches to the +power pad of the Teensy RTC backup on the main PCB.

Bluetooth Module (Optional – excludes use of GPS module)
The Bluetooth module is placed into the front part of the lid so that the underside of the pins are positioned in the slot as shown in the photo and it rests flat. Take the Bluetooth module clamp and install it so that the Bluetooth module fits inside the cutout. It is a snug fit so be sure it is fully seated. Use two 2-28 x 1/4” thread rolling screws to secure it in place.

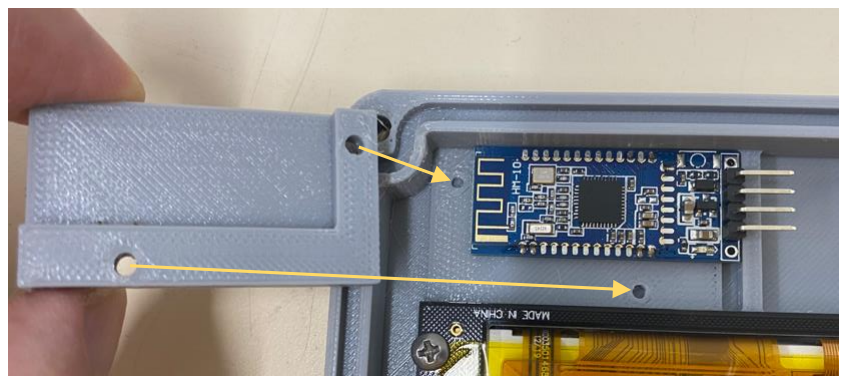
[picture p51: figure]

Bluetooth module placed in position for installation. The clamp flips over from the orientation shown and the holes align with the holes in the lid as indicated by the arrows.

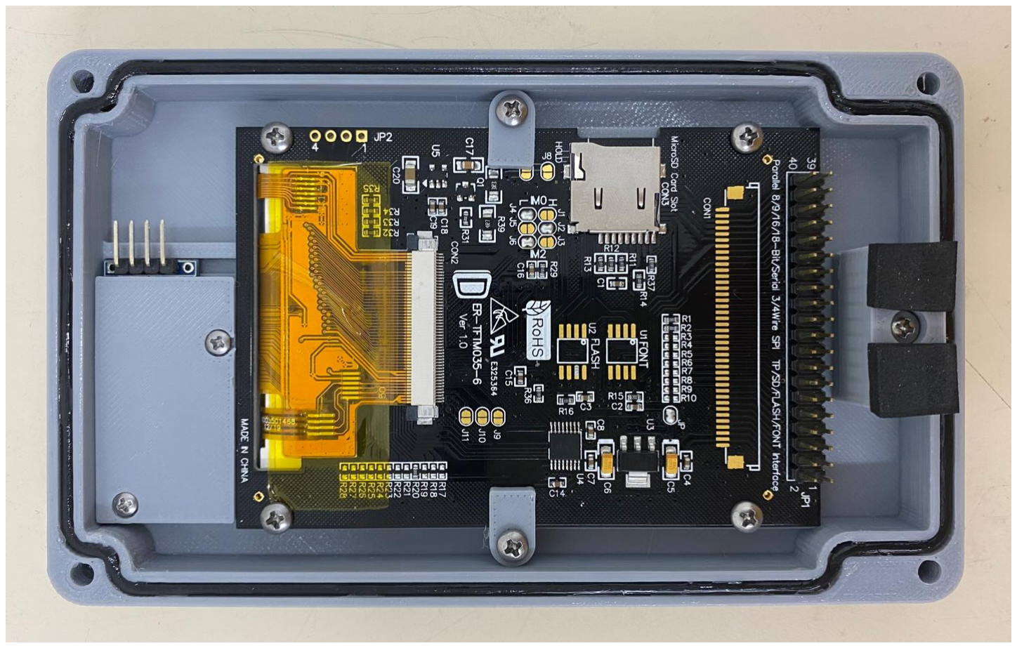
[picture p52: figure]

Main enclosure lid with everything installed (including a Bluetooth module) and ready for final assembly.

### Final Assembly

Get the microSD card ready. Insert it into a computer and verify that it is formatted as FAT32. If not, reformat it. t is highly recommended to use the D Association’s official D Formatter utility which can be downloaded here: https://www.sdcard.org/downloads/formatter/. Once formatted, copy the “cvfont32.bin” file to the micro D card so you don’t have to remove the card later for the initial aveatron software setup. nstall the card in the Teensy’s micro D slot.

Next, plug the 40-pin ribbon cable into the connector on the main PCB. Be careful that it’s centered, since it’s possible to accidently offset it to the side while plugging it in and have the pins offset by one position in the connector. The ribbon portion should extend toward the front over the main PCB away from the battery. Fold the cable in half so it folds back on itself with the connector on the other end pointing upward so that it can rest on top of the connector to the main PCB (see photo below). Be sure it has a good crease, so the fold is fairly tight and does not press down on the reset button on the Teensy.

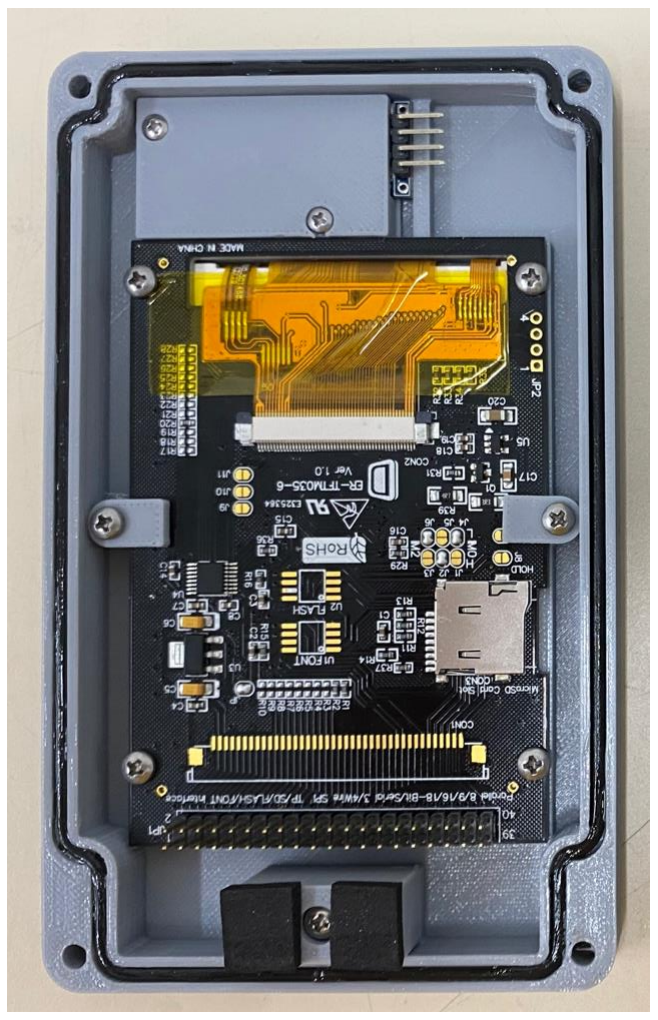
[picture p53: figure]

Caveatron SV ready for final assembly.

Connect the 40-pin ribbon cable to the LCD Touchscreen module again being sure the pins are not offset. Finish by connecting the battery cable to its connector.

Before attaching the lid, plug a USB cable into the external connector and plug it into a USB power source. The ring LED around the power switch should illuminate red. Now press the power switch and you should see several LED lights come on inside the box.

Grease the O-ring on the lid and carefully lower it onto the base, being sure that all the wires are inside and not being pinched. Use four 6-32 x 1/2” flat head screws to attach it. Tighten these down.

Wrist Strap Lanyard (Optional)
A slot is provided in the right rear of the lid to install a wrist strap. Squeeze the loop end of the strap to a point and work it into the slit. Continue to press and wiggle it as it works up and around the slot until it comes back out through the other slot. Pull the other end of the strap through the small loop to secure it.

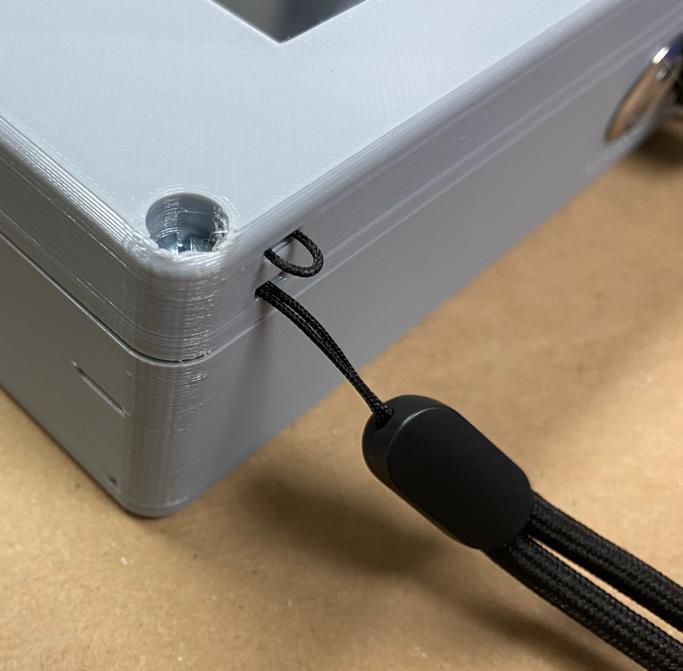
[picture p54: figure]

Installing the wrist strap lanyard.

Charge the Battery
Plug the USB cable in and fully charge the battery. When the ring LED on the switch turns green (or sometimes yellow) the battery is fully charged.

The Caveatron SV assembly process is now complete!

### Software Installation and Setup

There are several steps remaining to prepare the Caveatron SV for use. These are described in other documents but the steps are summarized below:

- Prepare to load code into the aveatron. Read the “Loading aveatron Firmware” instructions and download the TyTools software.
- Load the Caveatron_Setup firmware appropriate for the Rev C Caveatron SV and run the setup process described in the “ aveatron etup & alibration nstructions” document.
- Load the Caveatron_v3xx firmware.
- Calibrate the Caveatron as described in the “ aveatron etup & alibration nstructions” document.

Your Caveatron SV is now ready to survey caves!

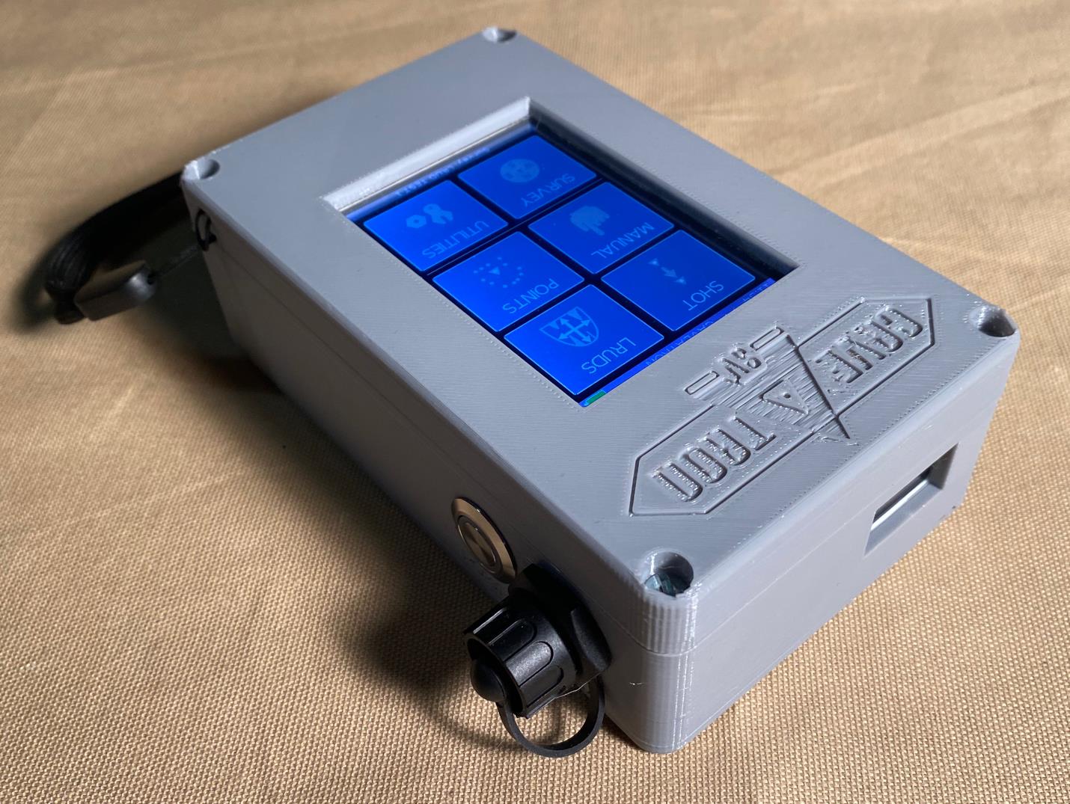
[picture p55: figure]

Fully assembled Caveatron SV.

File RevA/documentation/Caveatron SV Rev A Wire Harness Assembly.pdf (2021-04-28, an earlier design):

### Caveatron SV Rev A - Wire Harness Assembly

Version: 2021-04-27

CAUTION: Do not pay attention to wire colors except where noted below. Pre-wired connectors are usually wired with arbitrary wire colors so will not be consistent. Be especially careful with two wire connectors to be sure you are not wiring it backwards (sometimes the black wire on these pre-wired connectors is in the positive position!)
Connectors, Pin Conventions, and General Notes
These connectors are used in the wire harnesses and the pin number convention is shown below:
- JST XH 2.54 5-pin connectors are used on the Laser Rangefinder (LRF), the Power Switch, and the Bluetooth module.
- JST XH 2.54 2-pin connectors are used for USB Power, USB Data, the Piezo Buzzer, and the Battery. JST XH (2.54 mm)

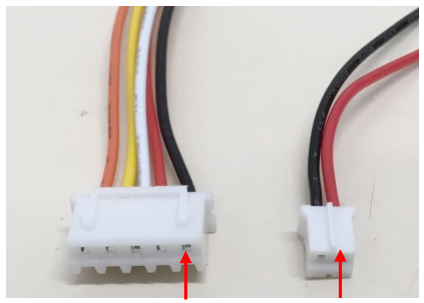
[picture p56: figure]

Pin 1 | Pin 1

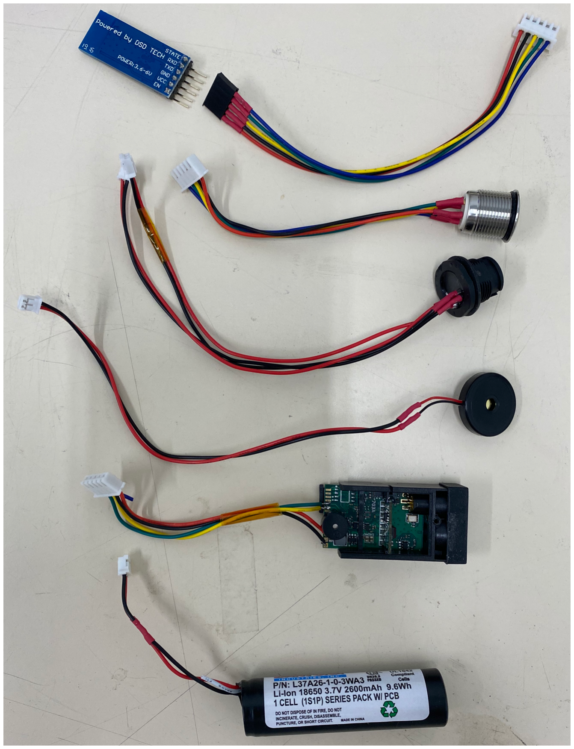
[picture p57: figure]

The photo at left shows examples of the wiring harnesses used in the Caveatron SV. It is highly recommended that heat shrink tubing be used on all solder interfaces and as strain relief on soldered pins. Kapton tape and/or small cable ties can be used for additional strain relief. Be extra careful when wiring the battery to avoid allowing the wires to touch.

Laser Rangefinder
Pin on PCB Connector | Description
1 | +3.0 V
2 | GND
3 | RX on Teensy / TX on LRF
4 | TX on Teensy / RX on LRF
5 | -
Length of Wire Harness: 7.5” for V+/GND, 7.75” for RX/TX, 7” for Power On.

### JRT 40m LRF Module (Small)

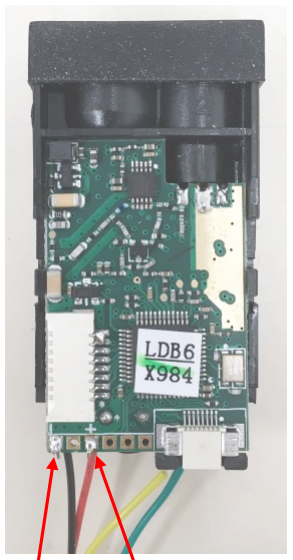
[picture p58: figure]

Power Switch

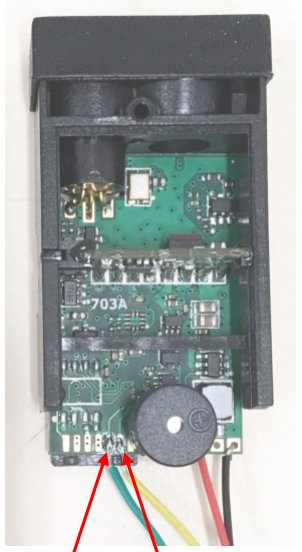
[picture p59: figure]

Pin on PCB Connector | Description
1 | +5 V (C+)
2 | Red LED Cathode
3 | Green LED Cathode
4 | Switch A
5 | Switch B
(Switch A and B do not have a polarity and can be reversed) Length of Wire Harness: 2.5”
GND | V+ | TX on LRF (RX on Teensy)
RX on LRF
(TX on Teensy)
Top View | Bottom View

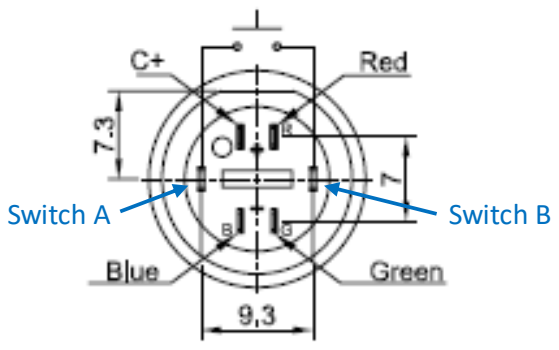
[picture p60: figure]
Switch A; Switch B

Piezo Buzzer
Pin on PCB Connector | Description | Piezo Buzzer Wire Color
1 | +V | Red
2 | GND | Black
Length of Wire Harness: 6.5”

Battery
Pin on PCB Connector | Description | Battery Wire Color
1 | +V | Red
2 | GND | Black
Length of Wire Harness: 2.75”

USB Connector
Note that pin 5 and pin G need to be shorted together with a small piece of wire.

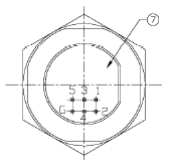
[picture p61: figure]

Pin on USB Connector | Description | Pin on 2-wire USB Power Connector | Pin on 2-wire USB Data Connector
1 | +5 V (VCC) | 1
2 | D- | | 2
3 | D+ | | 1
4 | -
5 | GND | 2
G | GND | 2
Length of Wire Harness (including USB Micro): 4.25”

Bluetooth Module
Pin on PCB Connector | Description
1 | Enable (on HC-05 only)*
2 | +5V
3 | GND
4 | RX on Teensy / TX on Bluetooth
5 | TX on Teensy / RX on Bluetooth
* Note: The enable pin is only used with the HC-05 bluetooth module. On the HM-10, this pin is not wired.

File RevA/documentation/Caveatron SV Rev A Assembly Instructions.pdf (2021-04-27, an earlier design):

## Caveatron SV Rev A Assembly Instructions

### Version: 2021-04-24

### Overview

This document provides instructions on how to assemble the Caveatron SV – the non-LIDAR version focused on traditional sketch-based cave survey. This version has a 3D printed enclosure and a custom printed circuit board (PCB) and requires cutting one acrylic part and soldering items to the PCB including a few smaller surface-mount components. The Caveatron SV includes an optional Bluetooth module that will be used in conjunction with the Android tablet-based sketch software, TopoDroid. If you do not plan to use this function, you do not need any Bluetooth components.

Some Tools Required:
- Band Saw (or other tool for cutting plastic)
- Soldering Iron
- Screw drivers
- Pliers
- Tweezers

Assembly Materials Required:
- Marine grade adhesive
- O-ring epoxy
- O-ring lubricant (synthetic grease)
- Soldering supplies including heat shrink tubing
- Adhesive-backed foam
- Tape (Kapton or electrical)

### Enclosure

3D Printed Parts
The enclosure parts are 3D printed. Detailed information about the parts and printing them can be found in the separate “Caveatron SV 3D Printed Parts Description” document. The material I used is PETG which is much more durable than PLA, but more flexible and easier to print than ABS. If the goal is to maximize durability, then ABS would probably be fine, but I would not recommend PLA.

There are 8 printed parts needed (7 unique parts) as summarized below and shown in the photo:

- Main Enclosure Base
- Main Enclosure Lid
- LRF Cradle Bracket
- LRF Clamp
- IMU Bracket
- LCD Clamp (2 pieces)
- Battery Clamp
- Bluetooth Clamp (optional)

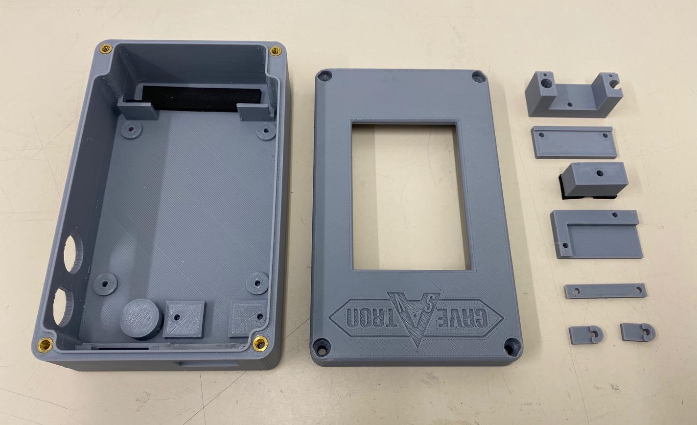
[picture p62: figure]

3D Printed Parts. Threaded inserts for attaching the lid are installed in the main enclosure base at left.

Preparing the Parts
After printing the parts and removing support material, a small amount of sanding with a fine grit sanding sponge or sandpaper may be desired o clean up the edges – especially on the main enclosure to give the edges a little more of a rounded edge for more comfort while holding it. There are sometimes residual stringing from the printing process that need to be removed.

Installing the Threaded Inserts
The parts have holes for either thread-rolling screws, for mounting smaller components, or for threaded inserts, where a more durable connection is required. Heat-set threaded inserts are installed using a soldering iron. Two sizes are used as indicated below:
- #6-32
- 4 in the Main Enclosure Base top side corners for attaching the lid
- ¼-20 (optional - for tripod mounting)
- 1 on the underside of the Main Enclosure Base

Before installing the inserts, have a matching screw ready to check that the insert if vertical. To install them, hand press them as far as you can into the hole and give them a few light taps with a tool. Press the soldering iron onto the top of the insert for a few moments to allow it to heat up the part and then start gently pressing and slightly wiggling the insert to encourage it to move deeper into the hole. Be careful not to the let the soldering iron slip and damage the 3D part surface. Keep pressing and wiggling until the insert is level with the top surface of the part as shown below. Remove the soldering iron and quickly thread in the matching screw a short distance and look to confirm that the screw sticks straight up from the surface. Be careful since the inserts are very hot! If it is angled by any significant amount, try to use the screw to straighten it out before the plastic cools and re-hardens. Otherwise leave in the screw and use the soldering iron to warm it back up to correct it (be careful to avoid getting burned).

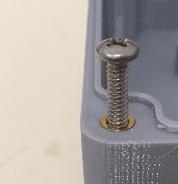
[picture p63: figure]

Use a large tip soldering iron to install the inserts. As shown In the photo at left, tilt the soldering iron along the edge of the insert or use a wide tip to be sure to not get the tip stuck inside the insert or it will pull out the insert once you have pressed it in. Be sure that the inserts are installed level with the surface. Use a matching screw to quickly confirm that the inserts are installed vertically and not tilted. If you are fast enough you can use them to correct any tilt before the plastic cools down. Be careful as the inserts are very hot!

Acrylic Window
There is 1 clear acrylic window that must be cut out and installed for the LRF window. After cutting it out, test the cut piece by placing it in position. Once you are satisfied with the fit, it is time to glue it into place. Use a marine grade or other waterproof adhesive. Place the epoxy on the inside walls of the enclosure base. Put in just enough to get continuous coverage but not too much or it will ooze out when you insert the window. Use a glove to press the window into place so as not to get fingerprints on it and being careful that no epoxy gets on the center part of the window. Press it tightly for several minutes to allow the epoxy to set up and clamp it. Allow it to cure for 24 hours.


LRF Window: Place epoxy around the perimeter of the window opening. Using a glove, press the window into place being sure not to get any on the open part of the window.

O-Ring Gaskets
A custom O-ring gasket is needed for the lid. This is cut from gasket cord and glued on the cut ends into an O-ring using O-Ring epoxy (regular cyanoacrylate can be used as well). Cut to the following length:
- 15” (38 cm)

When epoxying the ends together, be sure to get an aligned joint. After the epoxy has cured for a few hours, smear a bit of lubricant along the length so that it will go in more easily and improve the seal. Press the O-ring into the slot starting at one location and working around the perimeter. Work it in so that it is consistent and not sticking out or pressed too far in at any location.

### Wire Harnesses

Detailed instructions for preparing the wiring harnesses can be found in the separate “Wiring Harness Assembly” document. There are 7 wiring harnesses:

- Laser Rangefinder
- USB Power
- USB Data
- Power Switch
- Piezo Buzzer
- Battery
- Bluetooth (optional)

### Electronics

Some electronics modules are intended to be attached to the printed circuit board (PCB) by plugging them into a female header while others are to be directly soldered onto the board. All of the components will need male header pins soldered onto them as well, though for some components, only selected pin locations are populated. Also, not all pin locations on the PCB are used. This is described below.


Schematic of Caveatron SV PCB

Teensy 3.6
If you ordered it with pins pre-soldered, you still need to add several male header pins as described below:
- Vb (1x1)
- A11,A10,AREF (1x3)

If you ordered it without pins, then you will also need to solder both full edge rows with a 1x24 set of pins. On the PCB, two 1x24 rows of female header sockets are soldered to the board along with one 1x1 female header sockets under Vb and one 1x3 female under A11-AREF.

Additionally, you need pins to make the USB connection. There are two options provided: two pogo pins or soldered 1x2 right angle header pins. If you use the pogo pins, they are quite long, so must be carefully soldered so that they are as close to vertical as possible to be sure they contact the pad and are not touching. If you use right angle headers, these will also have to be carefully aligned so that they can insert into the female header socket that you will need to solder to the PCB. (Note the USB pads have a 2 mm spacing, not 0.1” like all other pins on the Teensy board.)


Teensy 3.6 Board. In addition to all of the 24 pin along both sides, the pins marked with blue arrows must be populated with male headers. Also, the pads indicated for the USB connection must either have a pogo pin installed on the PCB underneath that aligns with these pads or solder a 1x2, 2 mm right angle header that aligns to a socket on the PCB.

Location to install either pogo pins or female headers on the PCB.

Voltage Regulators (5V)
All pins on this board are populated with a 1x3 male header and is soldered directly to the PCB at the location marked 5V PWR. Pay special attention to be sure to get its orientation correct.

Voltage Regulators (LRF)
All pins on this board are populated with a 1x4 male header and is soldered directly to the PCB at the location marked LRF PWR.

Graphics Module (SPI Flash IC)
All pins on this board are populated (1x6) and it is soldered directly to the main PCB at the location marked GRAPHIC IC.

Pads for USB
connection
(pogo pins
contact or
soldered right
angle headers)

Install extra pin

Install extra pins

Install pogo pins here

Install 2mm female
header here

MinIMU/AltIMU
All 5 pins along one edge of the board are populated with a 1x5 male header and it is plugged into a 1x5 female header socket that is soldered to the PCB at the location marked MinIMU/AltIMU. (The inset SA0 pin is not used.) This component is additionally attached to the PCB with the IMU bracket. Since the positioning of this component is more important than the others (to get the compass orientation correct), the following procedure should be followed. First solder the female headers to the PCB. Insert the male headers into the socket without soldering them to the IMU. Attach the IMU board to the IMU bracket with one (MinIMU) or two (AltIMU) 2-28 x 1/4” long thread rolling screws. Place the IMU and bracket onto the main PCB (with the tops of the pins through the IMU board pin holes) and attach the IMU bracket to the PCB with two more 2-28 x 1/4” screws from the underside. Finally, solder the pins to the IMU board.

A location is provided next to the IMU pins on the PCB to solder a 10K surface mount resistor on the power inputs for the IMU. This is not required by highly recommended. Installing this resistor prevents a problem where the IMU does not power up properly if the Caveatron is turned on within a few seconds after being turned off.

Power Switch Board
For this board, solder a 1x6 male headers to one side and a 1x7 male header to the other side. This component is soldered directly to the main PCB at the location marked PWR SWITCH.

Battery Monitor Resistors
Two surface mount resistors are soldered to the two indicated pads to serve as the battery monitor. Note that the two resistors have different values so be sure to install the correct one on the correct pads.

Location to battery monitor resistors.

Other Parts & Connectors
The coin cell battery holder is soldered directly to the PCB in the location marked RTC BATT onto the surface mount pads. The plastic pins in the base of the battery holder align to the holes in PCB to hold it in place while soldering it.

A 2x20 female header socket is soldered to the PCB at the location marked LCD DISPLAY.

Three 5-pin JST connector sockets are soldered at the locations marked LRF (J5), SWITCH (J4), and (optionally) BLUETOOTH (J9). Four 2-pin JST connector socket are soldered at the locations marked

3.3k 1206

## resistor

10k 1206

## resistor

BATTERY (J8), BUZZER (J7), USB DATA (J3), and USB PWR (J2). Be sure to the note the JST socket key orientation as shown on the PCB silkscreen to install them correctly.

Li-Ion Charger Module
The component must have a small modification preformed before installation or it will not function. The two indicated pins in the illustration below must be shorted together either with a solder bridge or soldering a 0 ohm surface mount resistor.

The charger board has 7 pins attached, four on the short side and three along the long side. It is then soldered directly to the PCB.


Li-ion Charger Module. The two pads indicated must be shorted together with a solder bridge or a 0-ohm resistor for it to function.

### Set the LRF Regulator Voltage

Before attaching the LRF, the output voltage of the adjustable regulator that powers the LRF needs to be set. Assuming you have not yet loaded any code onto the Teensy, you should be able to do this by plugging in the battery and connecting a voltmeter to the two most interior pins on the LRF JRT connector (J2) -the plus voltage pin (marked on the PCB with a “+“, right next to the J2 label) and the minus pin right next to it. Press the small button on the Power Switch Board to turn the system on or off. Use a small screwdriver to adjust the pot on the voltage regulator until the voltage reads 3.0 volts.

Short across
these pads

To set the LRF regulator
voltage, measure across
these two pins.

+


PCB with all components installed.

### Main Enclosure Base Assembly

General note: When installing the thread rolling screws, it can be helpful to start the holes a little bit with the screw first before trying to install the part.

Circuit Board
Before installing the PCB, trim off the extra pin lengths on the underside of the PCB being sure none stick down further than the height of the support points in the enclosure base. The main PCB is installed using four 4-20 x 1/4” thread rolling screws (one in each corner). You will need washers to prevent the screws from bottoming out in the holes which had to be shallow to avoid going too deep. Be sure that it is square to the enclosure by inserting each screw part way and then pressing back on the board from the front so that it is not skewed with respect to the walls.

Buzzer
The piezoelectric buzzer is installed into the slot along the front wall of the enclosure. The buzzer opening faces outward toward the enclosure wall. Be sure the wires come out toward the top right of the enclosure as shown. Press it into the slot and then install the buzzer clamp. Use two 2-28 x 1/4” thread rolling screws to attach it. The end with the slight inset cutout around the hole goes toward the LRF window. Route the wires right along the front of the PCB behind the LRF mount so they can slightly slide under the corner of the PCB to hold them in place as shown in the picture on the next page.

Insert the piezo buzzer into the slot (left) and then install the bracket (right).

USB Connector
The USB connector is inserted from the inside of the enclosure. It is keyed so it can only be inserted one way. Take the nut off first and be sure the gasket is in place on the connector. When installing it, be sure the piezo buzzer wires are not getting caught by the connector. After sliding the connector into the enclosure hole, install the USB connector cover by sliding it over the threaded part of the connector from the outside. Be sure to position it, so the connecting piece is toward the bottom front as shown. Screw on the nut and tighten it down. Route the wires in front of the LRF mount under the LRF window as shown in the photo on the next page. A cable tie is helpful to keep the wires together.

Power Switch
The power switch is inserted from the outside of the enclosure. Be sure the rubber gasket that comes with it is placed on the switch body before installing it. Once in place, slide the nut over the cable and thread it onto the rear of the switch and tighten it into place. This wire harness goes across the top of the PCB to its connector as shown in the picture on the next page.


Installation and wire routing of the power switch, USB connector, and buzzer (left) and as seen from the exterior (right).

Laser Rangefinder
The LRF is installed in a cradle bracket that is in turn installed into the main enclosure base. When installing be sure to try to get all the parts as square to the enclosure as possible. The first step is to attach the bracket to the LRF. Look for a small hole in the front center of the LRF on one side as indicated by the arrow in the picture below. The cradle bracket has a countersunk screw hole which is aligned with the LRF and a 2-28 x 1/4” thread rolling screw is used to attach it. Flip the cradle bracket over and align the two large holes with the holes on the LRF mount (visible in the picture on the previous page). Attach it with two 4-20 x 1/2” thread rolling screws. Finally, install the clamp on top of the cradle bracket as indicated in the photo below with two 2-28 x 1/4” screws.


Installing the LRF. Attach the LRF to the bracket cradle (upper right) from the underside with a screw into the hole indicated (upper left), To install it in the enclosure, two 4-20 screws will go into the two large holes (lower left) and finally, the clamp will attach on top in the two small holes as indicated (lower left). The fully installed LRF is shown (lower right).

Battery
The battery goes in the large slot in the rear of the enclosure. To be sure it is tightly held and cannot slide around, a piece of adhesive backed foam is placed along the bottom of the battery slot. You may also need a piece of foam on one or both of the vertical parts depending on the battery’s fit. Orient the battery and insert it so that the wire harness goesinto the slit on the left front corner of the battery slot (as viewed from the rear of the enclosure). The battery will be fully secured by a bracket installed in the lid.


Foam adhesive backed pads to hold the battery (left) and the battery installed (right). This battery needed an additional piece of foam installed on the right-hand vertical piece.

Complete the enclosure base by installing the CR1220 battery into the coin cell battery holder. Plug in all connectors except for the battery which will be plugged in during final assembly. Be sure all wires are routed and reasonably secured.

Main enclosure base with everything installed.

### Main Enclosure Lid Assembly

Touchscreen LCD Display
The touchscreen LCD display goes in the lid of the Main Enclosure and connects to the main PCB by a 40-pin ribbon cable. Start by installing the screen protector which must be cut to size. The screen protector in the Bill of Materials is the correct width and only needs to be cut to the follow length:

Screen Protector Length: 3 5/16”

Now remove the protective film on the display. Be careful not to touch the display or get any dirt particles on the display until you get the screen protector installed. For the screen protector, peel the cover film off of screen side, being sure not to touch or get any dirt particles on the exposed part of the protector. Install the protector, lining it up with the bottom end of the LCD (the end opposite the pins). Be sure to line it up with the actual top end of the display module (covering the white frame part) which is slightly beyond the end of the actual screen – this gives it a bit more coverage for the silicone to seal to it. Slowly lower the protector across the length of the display, keeping it aligned to the edges and not getting bubbles in the middle of the screen. Once on, smooth out the edges and then peel off the top covering on the protector and smooth out again if you need to.

Not to edge of screen

Preparing the Touchscreen Display. Cutting the screen protector to length (center with cut piece on the bottom) and place it on the screen (right). Be sure that the top of the protector is aligned with the white frame that is surrounds the display.

Before installing the screen, check the fit. Place it in the cutout as shown and be sure the screw holes line up. For best fit, slide it as far toward the front as possible (the end with the slot for the LIDAR module cable). When viewed from the top, you should not see any of the white frame of the display module, as shown below. Pull out the display and prepare to place silicone sealant around the display perimeter. A syringe is recommended but you could use a toothpick or other method – just be sure to get a thin, smooth

Align to top edge of white frame bead all the way around the edge so that you get continuous coverage as shown. Don’t put on too thick of a bead or it will ooze out from under the screen edges when you screw it down in the next step.

Incorrect –; white frame is visible
Correct –; white frame is not visible

Positioning the touchscreen module – from the back when inserted into the cutout (left) and positioning with the white frame not visible from the front – incorrect (top right) or correct (bottom right).

Once the silicone bead is applied, line up the display at the front end so that you
can tilt and press it down at the right spot in the cutout in a single movement (if
you have to slide it, you might end up smearing silicone onto the visible part of the screen). Use four 4-20 x 1/4” thread rolling screws – one in each corner to secure it. Note that the holes in the LCD module are a little bit small and you will need to use a little bit of force to get the screws to go through. Start, but don’t tighten these down until you have all screws started. Finish tightening them. Now insert two more 4-20 x 1/4” screws into the touchscreen display clamps, as shown, so that the lip on the clip will go over the display module PCB when inserted. Install and tighten the screws. Check the topside of the screen and clean up any excess silicone. Allow the silicone to cure overnight.

LCD clamp screw
orientation


Add a silicone bead around the inside of the display cutout in the main enclosure lid (left). Screen installed from the backside (center) with the clamps. Be sure not to put on too much silicone so it does not ooze out onto the screen and clean up any that does.

Battery Clamp
The battery clamp installs on the raised section right behind the LRF module using a single 4-20 x 1/2” thread rolling screw. Add pieces of adhesive backed foam as shown which will press down on the battery.


Battery clamp installed with adhesive backed foam added.

Bluetooth Module (Optional)
If you plan to install the Bluetooth module, place it into the front part of the lid so that the underside of the pins are positioned in the slot as shown in the photo and it rests flat. Take the Bluetooth module clamp and install it so that the Bluetooth module fits inside the cutout. It is a snug fit so be sure it is fully seated. Use two 2-28 x 1/4” thread rolling screws to secure it in place.


Bluetooth module placed in position for installation. The clamp flips over from the orientation shown and the holes align with the holes in the lid as indicated by the arrows.


Main enclosure lid with everything installed and ready for final assembly.

### Final Assembly

Get the microSD card ready. Insert it into a computer and verify that it is formatted as FAT32. If not, reformat it. It is highly recommended to use the SD Association’s official SD Formatter utility which can be downloaded here: https://www.sdcard.org/downloads/formatter/. Once formatted, copy the “cvfont32.bin” file to the microSD card so you don’t have to remove the card later for the initial Caveatron software setup. Install the card in the Teensy’s microSD slot.

Next, plug the 40-pin ribbon cable into the connector on the main PCB. Be careful that its centered, since it’s possible to accidently offset it to the side while plugging it in and have the pins offset by one position in the connector. The ribbon portion should extend toward the front over the main PCB away from the battery. Fold the cable in half so it folds back on itself with the connector on the other end pointing upward so that it can rest on top of the connector to the main PCB (see photo below). Be sure it has a good crease, so the fold is fairly tight and does not press down on the reset button on the Teensy.


Caveatron SV ready for final assembly.

Connect the 40-pin ribbon cable to the LCD Touchscreen module again being sure the pins are not offset. Finish by connecting the battery cable to its connector.

Before attaching the lid, plug a USB Mini cable into the external connector and plug it into a USB power source. The ring LED around the power switch should illuminate red. Now press the power switch and you should see several LED lights come on inside the box.

Grease the O-ring on the lid and carefully lower it onto the base, being sure that all the wires are inside and not being pinched. Use four 6-32 x 1/2” flat head screws to attach it. Tighten these down.

Wrist Strap Lanyard (Optional)
A slot is provided in the right rear of the lid to install a wrist strap. Squeeze the loop end of the strap to a point and work it into the slit. Continue to press and wiggle it as it works up and around the slot until it comes back out through the other slot. Pull the other end of the strap through the small loop to secure it.


Installing the wrist strap lanyard.

Charge the Battery
Plug the mini-USB cable back in and fully charge the battery. When the ring LED on the switch turns green (or sometimes yellow) the battery is fully charged.

The Caveatron SV assembly process is now complete!

### Software Installation and Setup

There are several steps remaining to prepare the Caveatron for use. These are described in other documents but the steps are summarized below:

- Prepare to load code into the Caveatron. Read the “Loading Caveatron Firmware” instructions and download the TyTools software.
- Load the Caveatron_Setup firmware appropriate for the display on your Caveatron and run the setup process described in the “Caveatron Setup & Calibration Instructions” document.
- Load the Caveatron_v2xx firmware.
- Calibrate the Caveatron as described in the “Caveatron Setup & Calibration Instructions” document.

Your Caveatron SV is now ready to survey caves!


Fully assembled Caveatron SV.

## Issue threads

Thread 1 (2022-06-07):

AltIMU Bracket v1.stl missing from mechanical folder

MrDibbley, 2022-06-07:
AltIMU Bracket v1.stl missing from mechanical folder for SV ( I guess its the same as the one in the normal caveatron folder ? )

Cheers

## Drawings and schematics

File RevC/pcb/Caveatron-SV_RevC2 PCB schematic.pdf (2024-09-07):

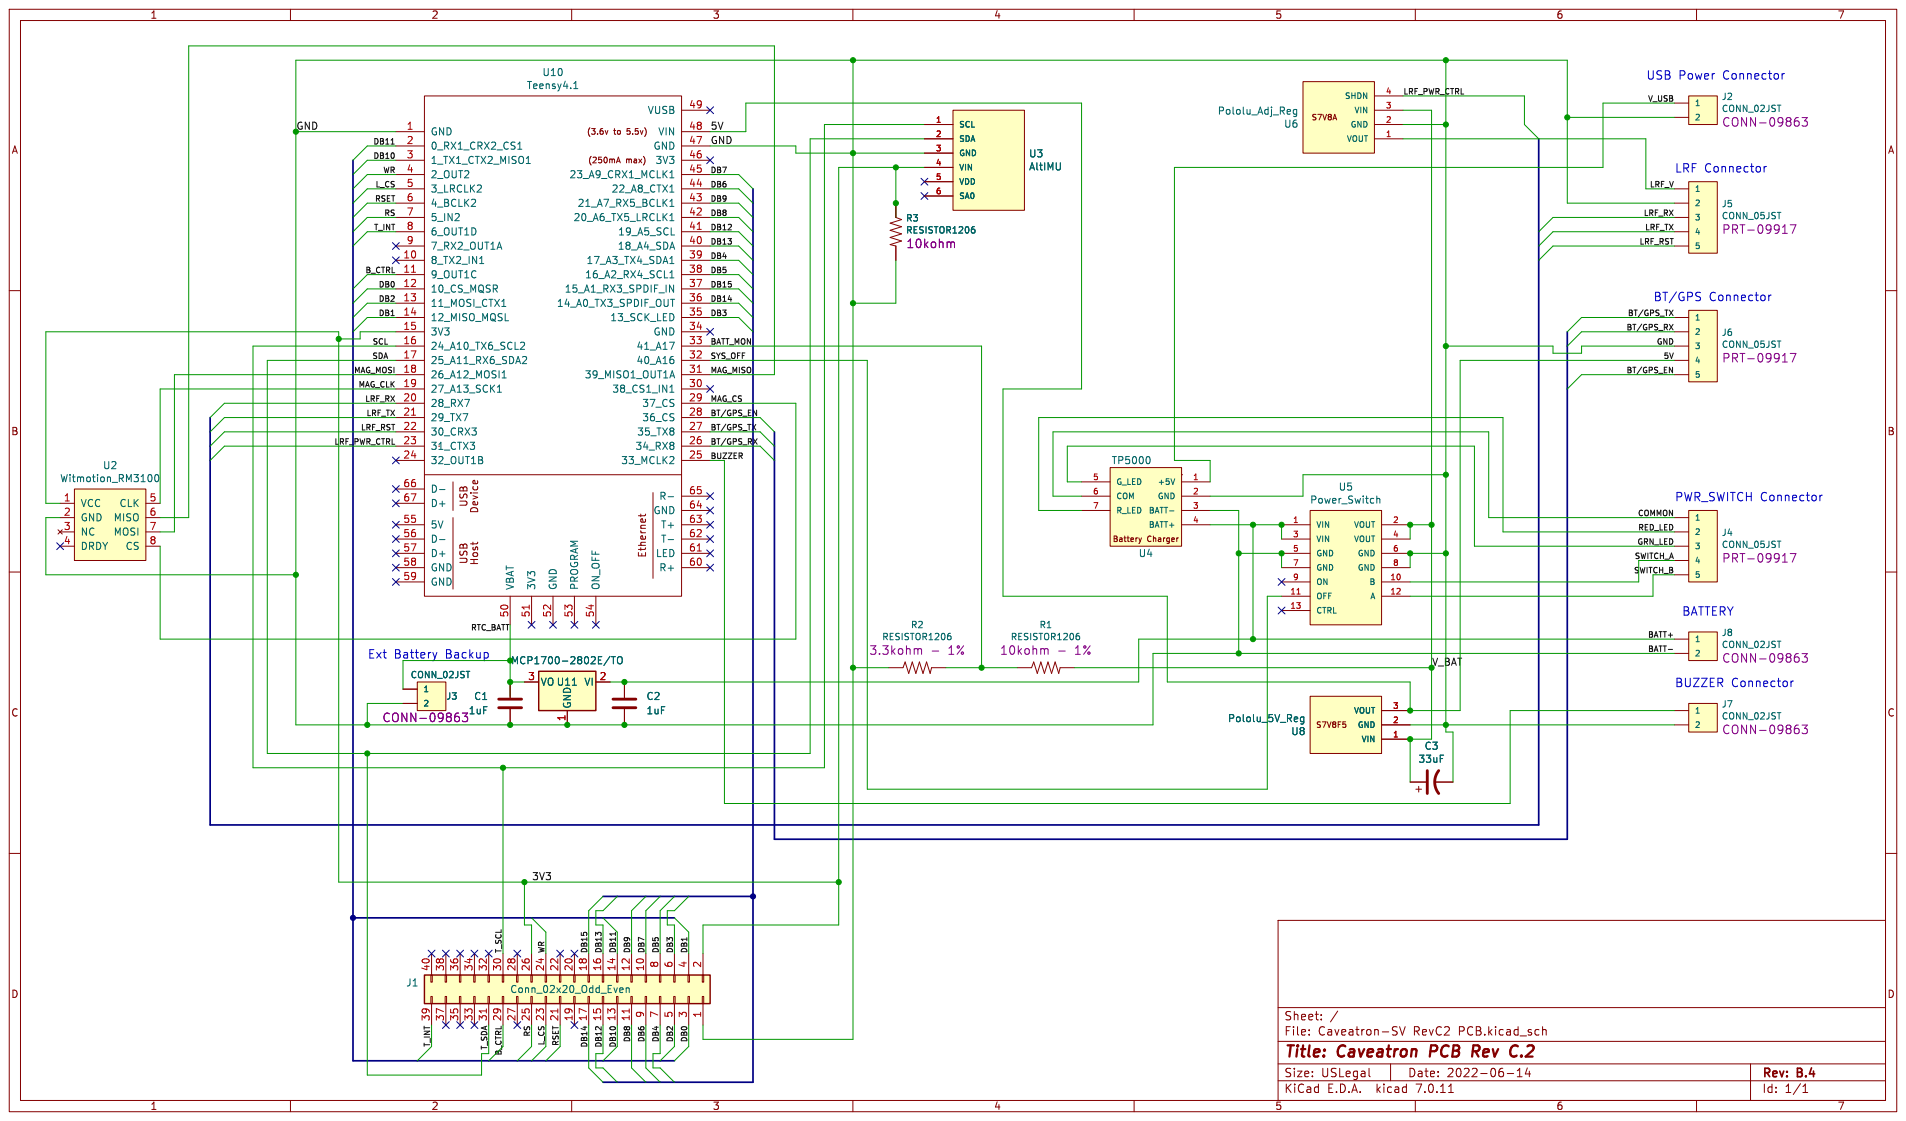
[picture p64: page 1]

Id: 1/1 Title: Caveatron PCB Rev C.2

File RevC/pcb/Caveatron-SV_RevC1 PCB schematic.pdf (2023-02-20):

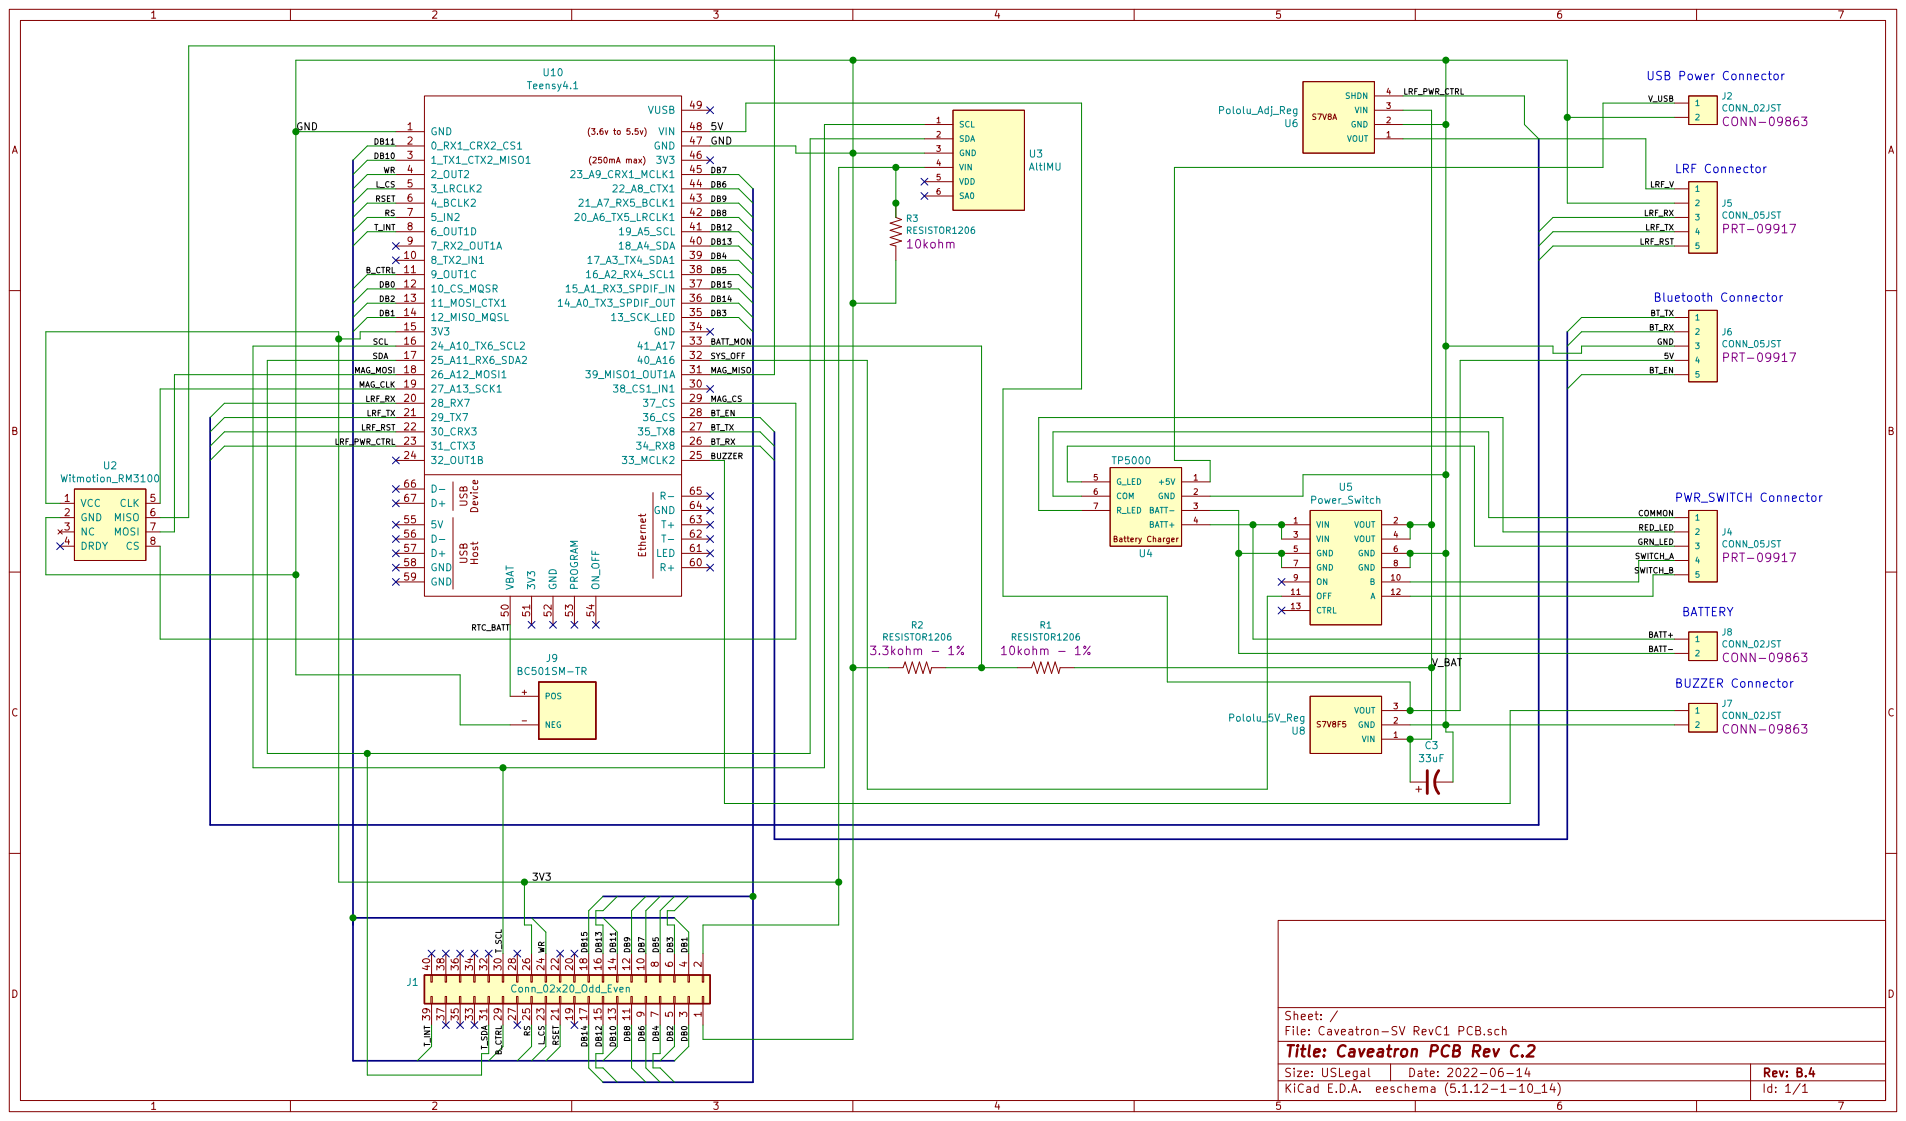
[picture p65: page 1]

25_A11_RX6_SDA2 17
26_A12_MOSI1 18
27_A13_SCK1 19
28_RX7 20 29_TX7 21 30_CRX3 22 31_CTX3 23

5V 55 D- 56 D+ 57 GND 58 GND 59

File: Caveatron-SV RevC1 PCB.sch Sheet: /
Id: 1/1 Title: Caveatron PCB Rev C.2

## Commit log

2021-08-04 Update Caveatron SV 3D printed parts description.pdf
2023-02-19 Add Rev C parts
    [LCD Clamp_RevC v3.step, LCD Clamp_RevC v3.stl, LRF Bracket Base_RevC v1.step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]
2023-02-20 Added Caveatron SV Rev C files
    [Battery Clamp v1.step, Battery Clamp v1.stl, Bluetooth Bracket v4.step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]
2024-01-02 Create GPS Bracket v2.stl
    [GPS Bracket v2.stl]
